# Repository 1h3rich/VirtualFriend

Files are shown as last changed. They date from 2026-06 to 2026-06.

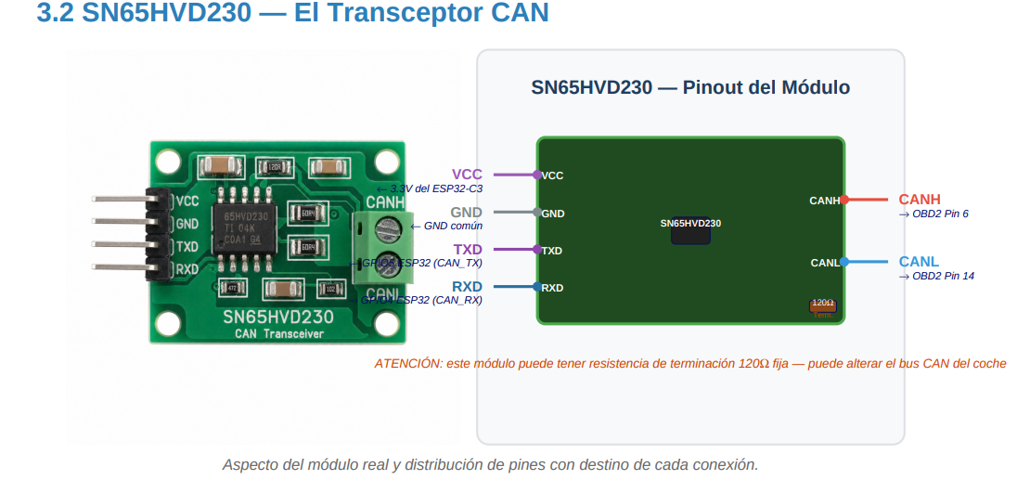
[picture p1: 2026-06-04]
VirtualFriendInf/Diagramas/DiagramaTranceptorCan.png

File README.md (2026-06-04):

# VirtualFriend

Copiloto virtual fisico para coche, basado en **M5Stack CoreS3** (ESP32-S3).
Cara animada en pantalla, voz sarcastica generada por IA, reacciona al
movimiento del vehiculo (IMU) y al toque del usuario.

## Hardware

- **M5Stack CoreS3** — pantalla tactil 320x240, altavoz AW88298, dos micros
  ES7210, microSD, IMU BMI270, bateria, WiFi.

## Arquitectura

```
[IMU/Touch] -> CtrlTask -> AnimTask  (cara animada en SD)
                       \-> AiTask   -> Cloudflare Worker
                                           |-> OpenAI gpt-4o-mini / Whisper
                                           \-> ElevenLabs TTS
[Touch]    -> MicTask   -> graba 3s WAV    -> AiTask -> Worker /listen
```

### Tareas FreeRTOS

| Tarea | Nucleo | Prio | Stack  | Funcion |
|---|---|---|---|---|
| AnimTask  | 0 | 2 | 20 KB  | reproduce GIF idle, eventos y expresiones |
| AiTask | 0 | 1 | 28 KB  | HTTP POST al Worker, TTS |
| MicTask | 1 | 1 | 12 KB  | grabacion I2S, genera WAV |
| CtrlTask  | 1 | 1 | 8 KB | IMU, touch, dispatch de eventos |

Sincronizacion: `g_audioMutex` serializa el acceso al I2S (mic/speaker
comparten bus). `g_micActive` y `g_aiThinking` activan los overlays en
pantalla.

## Estructura

```
src/
  main.cpp              entrypoint, setup y CtrlTask
  Config.h              umbrales IMU, credenciales WiFi/Worker
  AnimationPlayer.*     reproduccion de GIFs + fallback vectorial
  FaceRenderer.*        cara vectorial cuando no hay SD
  ExpressionManager.*   parametros de expresion (ojos, boca, color)
  SensorMonitor.*       IMU: detecta acelerada, frenada, bache
  MicManager.*          grabacion 3s WAV @ 16kHz
  SpeechManager.*       decode MP3 (minimp3) + reproduccion
  AiManager.*           cliente HTTP del Worker, gestiona expresiones IA
  SoundManager.*        beeps de eventos y alertas
  minimp3.h             header-only MP3 decoder
```

## Compilar y subir

```sh
pio run                       # compilar
pio run --target upload       # compilar + subir al M5Stack
pio device monitor            # ver logs por serie
```

El puerto USB suele estar en `/dev/ttyACM0` o `/dev/ttyACM1`.
Ajusta `upload_port` / `monitor_port` en `platformio.ini` si cambia.

## Endpoints del Worker

- `POST /` — evento de sensor (HARD_ACCEL, HARD_BRAKE, BUMP).
- `POST /listen` — audio WAV del micro -> Whisper -> respuesta IA.

Ambos devuelven `audio/mpeg` (MP3 22050Hz) con headers `X-VF-Expression`
y `X-VF-Sound`.

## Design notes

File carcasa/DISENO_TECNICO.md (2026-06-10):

# VirtualFriend — Diseño Técnico de Carcasa

## 1. Concepto general

Carcasa en dos piezas para salpicadero de coche. Cuerpo principal con apertura frontal
(pantalla + rejilla altavoz) y tapa trasera desmontable con tornillos M3. El conjunto
está inclinado 8° hacia atrás para que la pantalla y el altavoz apunten directamente
al conductor/copiloto. El zócalo de base sobresale lateralmente para mayor estabilidad
y admite velcro o adhesivo 3M en la cara inferior.

---

## 2. Distribución interna de componentes

```
┌─────────────────────────────────────────────────────────────────────┐
│  FRONTAL (cara visible)                                             │
│                                                                     │
│  ┌───────────────────────────────────────────────────────────────┐  │
│  │  VENTANA PANTALLA M5Stack  50.5 × 42 mm                      │  │
│  │                                                               │  │
│  │  Asiento M5Stack CoreS3                56.5 × 56.5 × 32.5    │  │
│  │  (retenido por 3 paredes laterales + base)                    │  │
│  └───────────────────────────────────────────────────────────────┘  │
│                                                                     │
│  ┌───────────────────────────────────────────────────────────────┐  │
│  │  REJILLA ALTAVOZ  72 × 33 mm (ranuras verticales 1.5mm)      │  │
│  │  Asiento altavoz con labio perimetral + espacio acústico      │  │
│  │  Amplificador MAX98357A en repisa lateral derecha             │  │
│  └───────────────────────────────────────────────────────────────┘  │
│                                                                     │
│  ┌─────────────────────────────────────────────────────────────┐    │
│  │  ZONA CAN/OBD (expansión futura)  40 × 35 mm               │    │
│  │  Delimitada por nervios internos, accesible desde tapa      │    │
│  └─────────────────────────────────────────────────────────────┘    │
└─────────────────────────────────────────────────────────────────────┘
```

---

## 3. Medidas exteriores

| Dimensión | Valor |
|---|---|
| Ancho | 112 mm |
| Alto | 88 mm |
| Profundidad | 52 mm |
| Radio esquinas | 4 mm |
| Inclinación | 8° |
| Zócalo (sobresale) | +8 mm c/lado |

---

## 4. Medidas internas (espacio útil)

| Zona | Dimensión |
|---|---|
| Interior general | 106.4 × 82.4 × 45.2 mm |
| Hueco M5Stack | 56.5 × 56.5 × 32.5 mm  |
| Hueco altavoz | 72 × 33 × 8 mm |
| Zona amplificador | 25 × 18 × 10 mm |
| Zona CAN/OBD futura | 40 × 35 × 20 mm |
| Paredes | 2.8 mm general / 3.0 mm base |

---

## 5. Ubicación del M5Stack CoreS3

- Posición: zona superior del cuerpo, centrado horizontalmente.
- Retenido por 3 paredes interiores (izquierda, derecha, superior) de 1.5 mm de grosor.
- La cara frontal (pantalla) queda alineada con la apertura de la carcasa.
- Margen superior: 4 mm (para fácil extracción).
- Cables salen por la parte inferior hacia el compartimento del amplificador y CAN.

---

## 6. Ubicación del altavoz

- Posición: zona inferior frontal, debajo del M5Stack.
- Separación entre M5Stack y altavoz: 4 mm (para paso de cables y disipación).
- Orientación: cono mirando hacia frontal (hacia el conductor).
- Asiento con labio perimetral de 1.5 mm para sellar con junta de espuma/goma.
- Cámara acústica detrás: ~8 mm de profundidad antes de la zona de amplificador.
- Rejilla frontal: ranuras verticales de 1.5 mm con separación de 2.5 mm, margen perimetral 4 mm.
- El cono del altavoz no toca plástico ni cables (mínimo 2 mm libre).

---

## 7. Ubicación del MAX98357A

- Posición: repisa interior lateral derecha, entre el asiento del altavoz y la zona CAN.
- Altura: a 9 mm del suelo interior (encima del asiento del altavoz).
- Accesible sin extraer el M5Stack (abriendo la tapa trasera).
- Cables que salen:
  - 5V / GND desde M5Stack
  - BCLK, LRC/WS, DIN desde pines I2S del M5Stack
  - + / - hacia altavoz (corto recorrido, altavoz justo encima)

---

## 8. Hueco futuro Jack 3.5mm

- Posición: lateral izquierdo del cuerpo, a media altura de la zona M5Stack.
- El agujero está **marcado pero cerrado** en el diseño actual (pared sólida).
- Basta con taladrar Ø7 mm para instalar el conector jack.
- Espacio interior reservado para DAC PCM5102A (~20×15×5 mm) cerca de ese lateral.
- El jack **no** vendrá de la salida amplificada; vendrá del DAC I2S futuro.

---

## 9. Hueco futuro Módulo CAN/OBD

- Posición: zona inferior del compartimento interior.
- Dimensiones reservadas: 40 × 35 × 20 mm.
- Delimitada por dos nervios verticales de 1 mm de alto (marcadores visuales, no estructurales).
- Accesible directamente al abrir la tapa trasera.
- Salida de cable: ranura inferior trasera de 20×4 mm ya perforada para paso de cable OBD2.
- No interfiere con el prototipo actual.

---

## 10. Sistema de cierre con tornillos

- 4 columnas M3 en las esquinas interiores del cuerpo.
  - Diámetro exterior columna: 6.5 mm.
  - Agujero interior: 2.5 mm (para roscar con macho M3 o insertar inserto de calor M3).
  - Altura: 12 mm.
- Tapa trasera con 4 agujeros pasantes M3 + avellanado para cabeza.
- Tornillos recomendados: **M3×12 cabeza avellanada** (ISO 10642 / DIN 7991).
- El labio de encaje (2 mm de profundidad, tolerancia 0.25 mm) centra la tapa antes de atornillar.

---

## 11. Sistema de fijación al salpicadero

El zócalo sobresale 8 mm por cada lado respecto al cuerpo. La cara inferior es plana.
Opciones de fijación:

| Opción | Descripción |
|---|---|
| Velcro industrial | Pegar en la base, pareja en el salpicadero |
| Adhesivo 3M VHB | Cinta doble cara de alta resistencia |
| Base antideslizante | Lámina de silicona pegada en la base (temporal) |
| Soporte articulado  | Adaptar brazo de ventosa/rejilla con tornillo M4  |

Para el soporte articulado: el zócalo tiene espacio suficiente para añadir un agujero
M4 centrado (modificar el parámetro y regenerar el STL).

---

## 12. Recomendaciones de impresión 3D

| Parámetro | Cuerpo principal | Tapa trasera |
|---|---|---|
| Material | PETG / ASA | PETG / ASA |
| Orientación | Cara frontal abajo | Cara exterior abajo |
| Capas | 0.2 mm | 0.2 mm |
| Relleno | 25–30% | 20% |
| Perímetros | 3–4 | 3 |
| Soportes | No necesarios | No necesarios |
| Temperatura cama | 70°C (PETG) / 100°C (ASA) | igual |

- **No se necesitan soportes** con la orientación indicada.
- La rejilla del altavoz y la ventana de pantalla se imprimen sin soportes al orientar cara frontal abajo.
- Las columnas de tornillo se imprimen en vertical → buen acabado de agujero.
- Si se usa ASA: imprimir en recinto cerrado para evitar warping.

---

## 13. Lista de piezas necesarias

### Piezas impresas
| Pieza | Cantidad | Archivo |
|---|---|---|
| Cuerpo principal | 1 | virtualfriend_carcasa.scad (PIEZA="cuerpo") |
| Tapa trasera | 1 | virtualfriend_carcasa.scad (PIEZA="tapa") |

### Ferretería
| Elemento | Cantidad | Especificación |
|---|---|---|
| Tornillo M3×12 avellanado| 4 | ISO 10642 acero/inox |
| Inserto de calor M3 | 4 | Ø4.5mm×5.7mm (opcional, mejor rosca) |
| Junta espuma altavoz | 1 | Cortar a medida 72×33mm, Ø3mm grosor |
| Velcro industrial | 1 par | 50×25mm mínimo |

### Electrónica interna
| Componente | Cantidad | Notas |
|---|---|---|
| M5Stack CoreS3 K128 | 1 | Ya disponible |
| Amplificador MAX98357A | 1 | Módulo breakout |
| Altavoz 4Ω/3W 70×31mm | 1 | CQRobot Ocean o equivalente |
| Cable Dupont hembra 6pin | 1 | Para conexión amp-M5Stack |

### Futuras ampliaciones (no necesarias ahora)
| Componente | Cantidad | Notas |
|---|---|---|
| Conector Jack 3.5mm PJ-3 | 1 | Montaje en panel, Ø7mm |
| DAC PCM5102A | 1 | Módulo breakout |
| Módulo CAN SN65HVD230 | 1 | Ya previsto en el proyecto |

---

## 14. Posibles problemas del diseño

| Problema | Causa probable | Solución |
|---|---|---|
| M5Stack no encaja / muy ajustado | Tolerancia de impresión variable  | Ajustar m5_w/m5_h ±0.3 mm en el .scad |
| Tapa trasera no cierra bien | Shrinkage del material | Reducir tapa_lip_gap de 0.25 a 0.15  |
| Resonancias del altavoz | Cámara acústica pequeña | Añadir espuma acústica en la cámara |
| Columnas de tornillo se rompen | Impresión a baja densidad | Subir perímetros a 4, relleno 40% |
| Calor en coche (verano, ASA) | PLA o PETG a >60°C | Usar ASA, evitar exposición solar directa |
| USB-C inaccesible | Posición errónea según orientación| Verificar antes de imprimir con mockup de papel |

---

## 15. Mejoras para una versión 2

1. **Inclinación variable**: añadir cuña de base intercambiable (5°, 10°, 15°) para distintas posiciones de salpicadero.
2. **Soporte articulado integrado**: brazo tipo "cuello de cisne" para montaje en rejilla AC o ventosa.
3. **Cámara acústica sellada**: compartimento trasero del altavoz completamente sellado con abertura tipo bass-reflex (tubo de 8mm).
4. **Gestión térmica**: ranuras de ventilación pasiva en laterales superiores.
5. **LED de estado**: agujero lateral pequeño (Ø5mm) para LED indicador de encendido/OBD.
6. **Tapa modular CAN**: cuando llegue el módulo CAN, tapa trasera con conector DB9 o conector OBD integrado.
7. **Canal de cables**: guías internas para organizar el cableado limpiamente.
8. **Etiqueta grabada**: texto "VirtualFriend" en relieve en la tapa trasera (fácil en OpenSCAD).

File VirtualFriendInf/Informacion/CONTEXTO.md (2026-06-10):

# CONTEXTO DEL PROYECTO — VirtualFriend
> Leer este archivo al inicio de cada sesión para tener contexto completo.
> Actualizar al final de cada sesión con lo que se ha hecho.

---

## QUÉ ES ESTE PROYECTO

**VirtualFriend**: copiloto virtual físico para coche. Un pequeño dispositivo con pantalla que acompaña al conductor, muestra una cara animada, tiene personalidad humorística/sarcástica, reacciona al movimiento del vehículo y, en fases avanzadas, lee datos reales del coche por OBD2/CAN.

**Carpeta del proyecto**: `~/virtualfriend/`
**Lenguaje**: C++ / Arduino Framework
**Objetivo actual**: prototipo funcional y ampliable, no producto comercial.

---

## HARDWARE

### Dispositivo principal (cara/voz/IA)
- **M5Stack CoreS3 K128**
  - ESP32-S3, pantalla táctil, Wi-Fi, BLE, altavoz, 2 micrófonos, cámara, IMU, magnetómetro, RTC, microSD, batería

### Dongle OBD2 propio (lector del coche)
- **ESP32-C3** — microcontrolador, TWAI/CAN + BLE
- **SN65HVD230** — transceptor CAN (traduce lógica 3.3V ↔ bus CAN del coche)
- **Conversor DC-DC 12V→5V** — alimentación desde OBD2 pin 16
- **Fusible 1A** — protección en el cable +12V
- **Cable OBD2 macho a cables abiertos**
- **Caja plástica ~100×60×30 mm** (nunca metálica)

### Pines OBD2 usados
| Pin | Señal | Descripción |
|-----|---|---|
| 4/5 | GND | Masa |
| 6 | CAN-H | Bus CAN High |
| 14  | CAN-L | Bus CAN Low |
| 16  | +12V  | Alimentación directa batería |

---

## ARQUITECTURA DEL SISTEMA

```
Coche → Puerto OBD2
  ↓ cable físico
Dongle OBD2 (ESP32-C3 + SN65HVD230)
  ↓ BLE (datos limpios, no tramas crudas)
M5Stack CoreS3
  → cara, voz, frases, IA, reacciones
```

**Datos que lee el dongle (fase inicial)**:
- RPM: PID 0x0C → `((A*256)+B)/4`
- Velocidad: PID 0x0D → `A` km/h
- Temperatura refrigerante: PID 0x05 → `A-40` °C
- Voltaje: PID 0x42 → `((A*256)+B)/1000` V

**Velocidad CAN**: 500 kbps (probar 250 si no responde)
**ID petición OBD2**: 0x7DF | **ID respuesta**: 0x7E8–0x7EA

**Formato BLE enviado por dongle**:
```
rpm=1850;speed=72;coolant=91   (texto simple para prototipo)
```
o JSON en fases avanzadas.

---

## PERSONALIDAD DEL COPILOTO

- Tono: humorístico, sarcástico, carismático, útil
- Se pone serio ante avisos importantes
- Ejemplos:
  - Aceleración fuerte → "Tranquilo, Fernando Alonso, que esto no es Nürburgring."
  - Temperatura alta → "Ojo. El motor se está calentando más de la cuenta."
  - Bache → "Ese bache no era parte del trayecto, era contenido descargable."

---

## FASES DE DESARROLLO

| Fase | Estado | Objetivo |
|---|---|---|
| 1 | Pendiente | M5Stack: cara animada, expresiones, frases, sonido, IMU. Sin OBD2. |
| 2 | Pendiente | Dongle: ESP32-C3 + SN65HVD230, leer RPM por Serial Monitor. Sin BLE. |
| 3 | Pendiente | Dongle: leer RPM + velocidad + temperatura + voltaje |
| 4 | Pendiente | BLE: dongle envía datos, M5Stack recibe |
| 5 | Pendiente | Integración: datos del coche cambian expresiones y activan frases |
| 6 | Pendiente | Caja física, montaje final, pruebas reales en coche |

---

## ESTRUCTURA DE CÓDIGO PREVISTA

```
virtualfriend/
├── dongle_obd2/
│   ├── src/
│   │   ├── main.cpp
│   │   ├── Config.h          ← pines CAN_TX/RX, velocidad CAN, nombre BLE
│   │   ├── VehicleData.h     ← struct {rpm, speed, coolantTemp, batteryVoltage, valid}
│   │   ├── CanManager.h/cpp  ← init TWAI, send/receive tramas
│   │   ├── ObdReader.h/cpp   ← pedir PIDs, convertir bytes a valores
│   │   └── BleServer.h/cpp   ← servidor BLE GATT, notificaciones
│   └── platformio.ini
└── m5stack_copilot/
    └── src/
        ├── main.cpp
        ├── FaceRenderer.h/cpp
        ├── ExpressionManager.h/cpp
        ├── PhraseEngine.h/cpp
        ├── SoundManager.h/cpp
        ├── SensorMonitor.h/cpp   ← IMU para baches/frenazos
        └── BleClient.h/cpp       ← recibir datos del dongle
```

**Config.h del dongle (orientativo)**:
```cpp
#define CAN_TX_PIN 5
#define CAN_RX_PIN 4
#define CAN_SPEED  500000
#define BLE_DEVICE_NAME "VirtualFriend_OBD"
```

---

## LIBRERÍAS PREVISTAS

| Dispositivo | Librería |
|---|---|
| ESP32-C3 dongle | ESP-IDF TWAI, Arduino BLE |
| Datos OBD2 complejos (VIN, DTCs largos) | TWAI_ISO-TP |
| M5Stack CoreS3 | M5Unified, BLE client |

---

## REGLAS DE SEGURIDAD (CRÍTICAS)

- Solo lectura de PIDs OBD2 estándar
- NUNCA escribir en ECUs, borrar DTCs, controlar ABS/airbag/DSG/inmovilizador
- NUNCA comandos propietarios del fabricante
- Siempre fusible 1A en +12V
- Medir con multímetro antes de conectar al coche (salida DC-DC debe ser 5.0V ±0.2V)
- Caja plástica, no metálica
- Si el coche muestra aviso → desconectar inmediatamente
- Si algo se calienta → desconectar inmediatamente

---

## LO QUE SE HA HECHO HASTA AHORA

### Sesión 1 (2026-06-02/03)
- [x] Leído y analizado `ConfeccionOBD2.txt` con el manual técnico del dongle
- [x] Generado PDF visual completo: `/home/rich/Escritorio/Proyecto/Manual_OBD2_Dongle.pdf`
  - Portada, índice, 12 capítulos, diagramas dibujados con reportlab:
    - Conector OBD2 con pines coloreados
    - Diagrama de bloques del sistema
    - Esquema de cableado completo estilo PCB
    - Estructura de trama CAN/OBD2
  - Tablas de pines, PIDs, conexiones, velocidades CAN
  - Pasos de montaje numerados, protocolo de pruebas, troubleshooting
- [x] Creado este archivo CONTEXTO.md

### Sesión 2 (2026-06-03)
- [x] Generado PDF de soldadura: `/home/rich/Escritorio/Proyecto/Manual_Soldadura_OBD2.pdf`
  - 12 imágenes reales generadas con IA (GPT-Image-2) de todos los componentes
  - Pinouts dibujados: ESP32-C3, SN65HVD230, DC-DC
  - Código de colores de cables detallado
  - Técnica de soldadura paso a paso con fotos
  - 9 pasos de montaje: fusible → DC-DC → ESP32 → SN65 → CAN → GND → verificación → caja
  - Tabla de verificaciones con multímetro
  - Resumen visual de todas las conexiones
- [x] Actualizado CONTEXTO.md

### Sesión 3 (2026-06-03)
- [x] Revisado `DiagramaDeCableado.png` original — errores detectados: CAN-H/CAN-L iban al DC-DC en vez del SN65, SN65 debajo del DC-DC con líneas confusas, diagrama recortado a la derecha (sin M5Stack), labels solapados
- [x] Generadas versiones corregidas del diagrama:
  - v2: `/home/rich/Escritorio/Proyecto/DiagramaDeCableado_v2.png` — layout con M5Stack, rutas CAN correctas (solapamientos parciales)
  - v3–v5: iteraciones con diseño de dos zonas (alimentación/CAN), calles Y exclusivas por señal, layout sin solapamientos
  - **Final**: `/home/rich/Escritorio/Proyecto/DiagramaDeCableado_v5.png` — aprobado, limpio
    - Canvas 1920×980, zona azul (alimentación) + zona verde (CAN/señales)
    - DC-DC y SN65HVD230 apilados (mismo X, diferente Y con hueco visual)
    - Cada señal en su propia calle Y: +12V=160, +5V=240, GND=340, 3V3=410, CAN-H=560, CAN-L=640, TX=720, RX=800, BLE=900
    - Leyenda completa + caja de puntos críticos en esquina derecha
- [x] Scripts generadores en `/tmp/gen_diagrama_v3.py` a `v5.py`
- [x] Revisado y rehecho `DiagramaTranceptorCan.png`:
  - Original: labels solapados, "RXDR" en vez de RXD, texto cortado, mal contraste
  - **Final**: `/home/rich/Escritorio/Proyecto/DiagramaTranceptorCan_v2.png`
    - Script en `/tmp/gen_diagrama_transceptor.py`
    - Foto real del módulo SN65HVD230 (AI-generada)
    - Bloque ESP32 (izq) + SN65 (centro, LÓGICA/BUS CAN) + OBD2 (der)
    - Cables con colores, flechas de dirección y pill labels
    - Nota sobre resistencia terminación 120Ω y cómo comprobarla

### Sesión 4 (2026-06-03)
- [x] Cloudflare Worker desplegado y funcional
  - Worker en `~/Proyectos/virtualfriend-worker/`
  - URL pública: `https://virtualfriend-worker.rykhjob.workers.dev`
  - Secrets en Cloudflare: `GEMINI_API_KEY` y `DEVICE_TOKEN`
  - DEVICE_TOKEN: `(ver src/Secrets.h — no publicar)`
  - IA: Gemini 2.5 Flash con thinking desactivado (`thinkingBudget: 0`)
  - Tests pasando (6/6)
  - Documentación en `Escritorio/Proyecto/cloudflare/CLOUDFLARE_WORKER.md`
- [x] Problema detectado y resuelto: Gemini 2.5 Flash consumía todos los tokens pensando → se desactivó el modo thinking
- [x] Problema TLS en CachyOS: TLS 1.3 + ECH falla en este equipo con curl. Usar `--tlsv1.2 --tls-max 1.2` para pruebas locales. El M5Stack no tendrá este problema.

### Sesiones 5-7 (2026-06-03/04) — Implementación Fase 1 completa
- [x] Estructura `virtualfriend/m5stack_copilot/` con PlatformIO, env `m5stack-cores3`
- [x] **FaceRenderer**: cara vectorial (ojos+boca) con 8 formas de ojo y 7 de boca; modo de fallback cuando no hay SD
- [x] **ExpressionManager**: 7 expresiones (NEUTRAL/HAPPY/SARCASTIC/SURPRISED/ALERT/SLEEPING/ANGRY) con FaceParams
- [x] **SensorMonitor**: lectura IMU BMI270 a 25Hz; detección de HARD_ACCEL/HARD_BRAKE/BUMP con umbrales calibrados + cooldown 3s
- [x] **AnimationPlayer**: reproducción de GIFs desde SD con AnimatedGIF; sprite M5Canvas 320×240 en PSRAM; bucle interrumpible; pickPath para variantes aleatorias
- [x] **SoundManager**: 5 efectos (STARTUP/BUMP/ACCEL/BRAKE/ALERT) con mutex trylock para no romper I2S
- [x] **MicManager**: grabación 3s WAV @16kHz mono en PSRAM; mutex con timeout 20s; retry de record(); indicador "HABLA AHORA" inmediato al tocar; visibilidad mínima 2000ms
- [x] **SpeechManager**: decode MP3 con minimp3 (header-only); reproducción via M5.Speaker.playRaw; espera 600ms post-audio dentro del mutex (evita eco→Whisper)
- [x] **AiManager**: cliente HTTPS al Cloudflare Worker; dos endpoints (`/` para eventos, `/listen` para audio); flag `g_aiThinking` con overlay "PENSANDO..."; beep de alerta en errores; expresiones IA `X-VF-Expression` → AnimEvent → GIF o vector fallback
- [x] Compilación OK: 22.6% RAM, 17% Flash. Subido al M5Stack.

### Migración a proyecto VS Code (2026-06-04)
- [x] Movido todo el código desde `~/virtualfriend/m5stack_copilot/` a `~/VirtualFriend/` (proyecto Git original)
- [x] Reemplazado `platformio.ini` Wokwi/esp32dev por `m5stack-cores3`
- [x] Eliminados `wokwi.toml` y `diagram.json` (CoreS3 no soportado por Wokwi)
- [x] Eliminado `PhraseEngine.h/cpp` (la IA genera las frases)
- [x] README.md actualizado con arquitectura, tareas FreeRTOS y flujo
- [x] Commit `9570856` en main: "Fase 1: M5Stack CoreS3 firmware completo"

### Próxima sesión (Fase 2: dongle OBD2)
- [ ] Crear `dongle_obd2/` con PlatformIO env ESP32-C3
- [ ] CanManager: init TWAI a 500kbps, send/receive tramas
- [ ] ObdReader: PIDs 0x0C/0x0D/0x05/0x42, conversión bytes→valores
- [ ] Probar con coche real (lectura sin BLE primero)

---

## NOTAS TÉCNICAS IMPORTANTES

- El SN65HVD230 puede tener resistencia de terminación CAN de 120Ω fija → puede interferir con el bus del coche → revisar si hay problemas de comunicación
- Alimentar ESP32-C3 por USB y VIN/5V simultáneamente puede ser problemático según la placa → en pruebas, usar solo una fuente
- No confiar en colores del cable OBD2 → identificar pines por posición física
- Pin 1 del OBD2 = arriba izquierda, pin 16 = abajo derecha
- Frecuencia de consultas OBD2 no debe ser excesiva → puede saturar el bus o provocar avisos en el coche

---
*Actualizado: 2026-06-04 (Fase 1 completa, código en ~/VirtualFriend/)*

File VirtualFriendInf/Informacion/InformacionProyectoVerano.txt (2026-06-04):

# Resumen del prototipo: Copiloto Virtual para coche

## 1. Descripción general del proyecto

El proyecto consiste en crear un **copiloto virtual físico para coche**, con aspecto de pequeño compañero digital. La idea es que acompañe al conductor durante los viajes, muestre una cara animada en pantalla, tenga personalidad humorística y sarcástica, pueda reaccionar al movimiento del vehículo y, en fases posteriores, leer datos reales del coche mediante OBD2/CAN.

El proyecto está pensado para desarrollarse en la carpeta:

```txt
virtualfriend
```

El lenguaje principal será:

```txt
C++ / Arduino Framework
```

El objetivo inicial no es crear un producto comercial perfecto, sino un **prototipo funcional y ampliable**.

---

## 2. Personalidad del copiloto virtual

El copiloto debe tener un tono:

```txt
Humorístico
Sarcástico
Carismático
Útil cuando haga falta
Capaz de ponerse serio ante avisos importantes
```

Ejemplo de comportamiento:

* Si el conductor acelera mucho:
  “Tranquilo, Fernando Alonso, que esto no es Nürburgring.”

* Si detecta temperatura alta del motor:
  “Ojo. El motor se está calentando más de la cuenta.”

* Si detecta un bache o frenazo:
  “Ese bache no era parte del trayecto, era contenido descargable.”

La personalidad no debe impedir que dé avisos importantes de forma clara.

---

## 3. Hardware principal del copiloto

El dispositivo principal elegido es:

```txt
M5Stack CoreS3 K128
```

Se eligió esta placa porque incluye muchos elementos ya integrados:

```txt
Pantalla táctil
ESP32-S3
Wi-Fi
BLE
Altavoz
Doble micrófono
Cámara
Sensor de proximidad/luz
IMU / acelerómetro / giroscopio
Magnetómetro
RTC
microSD
Batería/base
```

Este dispositivo será la parte visible del copiloto:

```txt
M5Stack CoreS3 = cara, voz, pantalla, IA, personalidad y reacciones
```

---

## 4. Prototipo Nivel 1

El primer prototipo debe ser simple. No debe depender todavía del OBD2 ni de datos reales del coche.

El Prototipo 1 consta de:

```txt
Encendido
Pantalla con cara
Cambio de expresiones
Frases predefinidas
Sonidos simples
Reacción a movimiento
```

### Objetivo del Prototipo 1

Crear un dispositivo que:

```txt
Se encienda correctamente
Muestre una cara animada
Cambie de expresión
Reproduzca frases o sonidos simples
Reaccione al movimiento usando sensores internos
```

### Componentes necesarios para Prototipo 1

```txt
M5Stack CoreS3 K128
Animaciones de cara
Frases predefinidas
Sistema básico de sonido
Lectura de sensores internos
Código en C++
```

### Cómo se abordará cada parte

#### Encendido

El M5Stack debe iniciar correctamente y mostrar una pantalla de bienvenida.

Ejemplo:

```txt
"Copiloto iniciado"
"Cargando personalidad..."
```

#### Pantalla con cara

La pantalla mostrará una cara simple. Puede empezar siendo muy básica:

```txt
Ojos normales
Ojos enfadados
Ojos sorprendidos
Ojos dormidos
Boca simple
```

No hace falta empezar con animaciones complejas. Primero importa que se pueda cambiar de estado visual.

#### Cambio de expresiones

El dispositivo tendrá distintos estados:

```txt
Normal
Feliz
Sarcástico
Alerta
Dormido
Asustado
Pensando
```

Cada estado cambiará la cara mostrada en pantalla.

#### Frases predefinidas

Al principio no se usará IA generativa. Se programará una lista de frases predefinidas.

Ejemplo:

```cpp
"Vaya conducción. No sé si aplaudir o rezar."
"Todo bajo control. Supuestamente."
"Estoy despierto. Más que algunos copilotos humanos."
```

#### Sonidos simples

El CoreS3 podrá reproducir sonidos breves:

```txt
Beep
Sonido de alerta
Sonido de confirmación
Sonido de arranque
Sonido de reacción
```

#### Reacción a movimiento

El M5Stack CoreS3 usará sus sensores internos para detectar:

```txt
Baches
Frenazos
Curvas bruscas
Golpes
Movimiento repentino
```

Esto no necesita OBD2. Se hace con acelerómetro/giroscopio.

Ejemplo:

```txt
Si detecta aceleración fuerte → cambia a cara sorprendida
Si detecta golpe/bache → reproduce frase sarcástica
Si no hay movimiento durante un rato → modo dormido
```

---

## 5. Prototipo Nivel 2: conexión con datos del coche

La siguiente fase consiste en leer datos reales del vehículo.

Hay dos opciones:

```txt
1. Adaptador OBD2 BLE comercial
2. Dongle OBD2 propio
```

Se ha decidido explorar la opción de **crear un dongle propio**, para no depender de un adaptador comercial y para aprender cómo funcionaría una versión de producción.

---

## 6. Arquitectura general con OBD2

La arquitectura sería:

```txt
Coche
↓
Puerto OBD2 debajo del volante
↓
Dongle OBD2 propio
↓ BLE
M5Stack CoreS3
↓
Cara, voz, frases, IA y reacciones
```

El puerto OBD2 permite acceder a datos básicos del coche mediante CAN/OBD2.

Datos útiles:

```txt
RPM
Velocidad
Temperatura del refrigerante
Voltaje
Carga del motor
Códigos de error
```

No se pretende leer “todo el coche”. El objetivo inicial es leer datos OBD2 estándar.

---

## 7. Dongle OBD2 propio

El dongle propio sería un pequeño dispositivo conectado al puerto OBD2 del coche. Su función será leer datos básicos del vehículo y enviarlos por BLE al M5Stack CoreS3.

La idea es:

```txt
Dongle OBD2 = lector técnico del coche
M5Stack CoreS3 = interfaz, personalidad y comportamiento
```

### Componentes del dongle propio

```txt
ESP32-C3
Módulo CAN SN65HVD230
Cable OBD2 macho a cables abiertos
Conversor 12V a 5V
Fusible / portafusible
Cables Dupont
Caja pequeña
Soldador / estaño / termorretráctil
Multímetro
```

---

## 8. Para qué sirve cada componente

### M5Stack CoreS3 K128

Es el cuerpo principal del copiloto.

Sirve para:

```txt
Mostrar la cara animada
Reproducir voz o sonidos
Escuchar mediante micrófono
Usar Wi-Fi para futuras APIs
Conectarse por BLE al dongle
Detectar movimiento con sus sensores internos
Ejecutar la lógica principal del personaje
```

---

### ESP32-C3

Es el cerebro del dongle OBD2.

Sirve para:

```txt
Leer datos del coche
Procesar respuestas OBD2/CAN
Enviar datos limpios por BLE al M5Stack
```

El ESP32-C3 no será visible para el usuario. Irá dentro de una pequeña caja conectada al OBD2.

---

### SN65HVD230 CAN Module

Es el transceptor CAN.

Sirve para que el ESP32-C3 pueda comunicarse físicamente con el bus CAN del coche.

El ESP32-C3 puede gestionar CAN/TWAI a nivel lógico, pero necesita un transceptor para conectarse a los cables reales del coche:

```txt
CAN-H
CAN-L
```

Sin este módulo, el ESP32-C3 no puede hablar correctamente con la red CAN del vehículo.

---

### Cable OBD2 macho a cables abiertos

Es el enchufe físico al coche.

Sirve para conectar el dongle al puerto OBD2 sin desmontar nada.

Pines importantes:

```txt
Pin 6  → CAN-H
Pin 14 → CAN-L
Pin 16 → +12V
Pin 4/5 → GND / masa
```

Este cable permite construir el dongle sin tener que desmontar salpicadero ni buscar cables CAN internos.

---

### Conversor 12V a 5V

El coche entrega 12V por el puerto OBD2, pero el ESP32-C3 no puede recibir 12V directamente.

Este módulo sirve para:

```txt
Bajar de 12V del coche a 5V seguros
Alimentar el ESP32-C3
Evitar quemar la placa
```

Conexión:

```txt
OBD2 pin 16 +12V
↓
Fusible
↓
Conversor 12V a 5V
↓
ESP32-C3
```

---

### Fusible / portafusible

Sirve para proteger el prototipo y el coche en caso de cortocircuito.

Debe ir entre el positivo del OBD2 y el conversor:

```txt
OBD2 pin 16 +12V
↓
Fusible 1A
↓
Conversor 12V a 5V
```

Fusible recomendado:

```txt
1A
```

También puede servir:

```txt
500mA
2A
```

No usar fusibles grandes tipo 20A o 30A para este circuito.

---

### Cables Dupont

Sirven para conectar módulos durante las pruebas.

Conectan:

```txt
ESP32-C3 ↔ SN65HVD230
SN65HVD230 ↔ cable OBD2
Conversor 5V ↔ ESP32-C3
```

Para pruebas están bien. Para un montaje más estable en coche, mejor soldar y aislar.

---

### Caja pequeña

Sirve para meter dentro el dongle y evitar que las placas y cables queden sueltos debajo del volante.

Tamaño recomendado:

```txt
100 x 60 x 25 mm
100 x 60 x 30 mm
```

Debe ser:

```txt
Plástica
No metálica
Fácil de taladrar
Con tapa
Suficientemente amplia para prototipo
```

---

### Soldador, estaño y termorretráctil

Sirven para dejar conexiones firmes y seguras.

Los cables Dupont son útiles para pruebas, pero no deberían quedar como montaje final dentro del coche.

---

### Multímetro

Es importante para comprobar:

```txt
Que el conversor entrega 5V y no 12V
Que no hay cortocircuitos
Qué cable corresponde a cada pin del OBD2
Que GND está bien conectado
```

Antes de conectar el ESP32-C3 al conversor, hay que medir la salida.

---

## 9. Conexión eléctrica del dongle

Esquema básico:

```txt
OBD2 pin 6  CAN-H  → CAN-H del SN65HVD230
OBD2 pin 14 CAN-L  → CAN-L del SN65HVD230

OBD2 pin 16 +12V
↓
Fusible 1A
↓
Conversor 12V a 5V
↓
5V del ESP32-C3

OBD2 pin 4/5 GND
↓
GND común del conversor, ESP32-C3 y SN65HVD230

ESP32-C3 GPIO TX CAN → TXD del SN65HVD230
ESP32-C3 GPIO RX CAN → RXD del SN65HVD230
```

---

## 10. Comunicación OBD2/CAN

Para leer datos básicos no hace falta interpretar todo el CAN del coche.

Se pueden hacer consultas OBD2 estándar.

Ejemplo: pedir RPM.

Petición CAN:

```txt
ID: 0x7DF
Datos: 02 01 0C 00 00 00 00 00
```

Significado:

```txt
02 = longitud de datos útiles
01 = modo OBD2 para datos actuales
0C = PID de RPM
```

Respuesta esperada:

```txt
ID: 0x7E8
Datos: 04 41 0C A B 00 00 00
```

Cálculo:

```txt
RPM = ((A * 256) + B) / 4
```

Otros PIDs útiles:

```txt
010C → RPM
010D → velocidad
0105 → temperatura refrigerante
010F → temperatura de admisión
0111 → posición del acelerador
03   → códigos de error
```

---

## 11. Software recomendado

Para el ESP32-C3:

```txt
Arduino Framework o ESP-IDF
TWAI/CAN
BLE
```

Librería/referencia útil:

```txt
TWAI_ISO-TP
```

Uso previsto:

```txt
TWAI directo → datos simples como RPM, velocidad y temperatura
TWAI_ISO-TP → mensajes más complejos como VIN o DTCs largos
```

Para el M5Stack CoreS3:

```txt
M5Unified / librerías de M5Stack
BLE client
Pantalla
Sonido
Sensores internos
Wi-Fi para futuras APIs
```

---

## 12. Comunicación entre dongle y M5Stack

El dongle ESP32-C3 enviará datos por BLE al M5Stack.

La idea es que el dongle no mande tramas crudas, sino datos limpios.

Ejemplo:

```json
{
  "rpm": 1850,
  "speed": 72,
  "coolant_temp": 91,
  "battery": 13.8,
  "errors": []
}
```

El M5Stack recibe esos datos y decide cómo reaccionar.

Ejemplo:

```txt
RPM > 3500 → cara sorprendida + frase sarcástica
Temperatura > 105 ºC → alerta seria
Velocidad alta → comentario
Error motor detectado → aviso
```

---

## 13. Fases de desarrollo recomendadas

### Fase 1: Prototipo visual básico

Objetivo:

```txt
Encender M5Stack
Mostrar cara
Cambiar expresiones
Reproducir frases
Detectar movimiento
```

Sin OBD2 todavía.

---

### Fase 2: Dongle OBD2 básico por Serial Monitor

Objetivo:

```txt
ESP32-C3 + SN65HVD230 + OBD2
Leer RPM
Mostrar RPM por Serial Monitor
```

Sin BLE todavía.

---

### Fase 3: Lectura de varios datos

Objetivo:

```txt
Leer RPM
Leer velocidad
Leer temperatura refrigerante
Leer voltaje si es posible
```

---

### Fase 4: Comunicación BLE

Objetivo:

```txt
ESP32-C3 envía datos por BLE
M5Stack CoreS3 recibe datos por BLE
```

---

### Fase 5: Integración con comportamiento del copiloto

Objetivo:

```txt
Los datos del coche cambian expresiones
Los datos del coche activan frases
Los sensores internos detectan baches/frenazos
```

---

### Fase 6: Caja y montaje físico

Objetivo:

```txt
Meter el dongle en caja
Aislar conexiones
Evitar cables sueltos
Hacer pruebas reales en coche
```

---

## 14. Casos de prueba ficticios

### Caso 1: Arranque correcto

Condición:

```txt
El M5Stack se enciende
```

Resultado esperado:

```txt
Muestra cara normal
Reproduce sonido de inicio
Muestra mensaje de sistema listo
```

---

### Caso 2: Cambio de expresión manual

Condición:

```txt
Se pulsa un botón o se activa un estado de prueba
```

Resultado esperado:

```txt
La cara cambia de normal a sarcástica
```

---

### Caso 3: Detección de bache

Condición:

```txt
El acelerómetro detecta movimiento brusco
```

Resultado esperado:

```txt
Cara sorprendida
Sonido breve
Frase sarcástica
```

---

### Caso 4: Lectura de RPM

Condición:

```txt
El dongle envía rpm = 3200
```

Resultado esperado:

```txt
El M5Stack muestra expresión alerta/sarcástica
Puede lanzar frase relacionada con revoluciones
```

---

### Caso 5: Temperatura alta

Condición:

```txt
coolant_temp > 105
```

Resultado esperado:

```txt
El copiloto cambia a modo alerta
Da un aviso claro y serio
```

---

### Caso 6: Sin conexión BLE

Condición:

```txt
El M5Stack no encuentra el dongle
```

Resultado esperado:

```txt
El copiloto sigue funcionando en modo básico
Muestra aviso: "Sin datos del coche"
No bloquea el sistema
```

---

### Caso 7: Datos inválidos

Condición:

```txt
El dongle envía valores nulos o erróneos
```

Resultado esperado:

```txt
El M5Stack ignora esos datos
Mantiene el último estado válido o vuelve a modo normal
```

---

## 15. Principios de seguridad

Durante el prototipo:

```txt
No escribir comandos peligrosos al coche
No intentar controlar módulos del vehículo
No modificar centralitas
No mandar comandos de programación
Solo lectura / consultas OBD2 estándar
Usar fusible
Medir voltajes antes de conectar
Aislar cables
No dejar placas sueltas bajo el volante
```

El objetivo es leer datos, no controlar el coche.

---

## 16. Objetivo final del prototipo

El objetivo final de esta fase es conseguir:

```txt
Un M5Stack CoreS3 funcionando como copiloto virtual
Un dongle OBD2 propio basado en ESP32-C3
Comunicación BLE entre dongle y M5Stack
Lectura básica de datos reales del coche
Reacciones visuales y sonoras según esos datos
Código organizado en C++ dentro de la carpeta virtualfriend
```

El prototipo debe priorizar:

```txt
Funcionamiento básico
Seguridad
Código entendible
Modularidad
Facilidad para ampliar
```

No debe priorizar todavía:

```txt
Carcasa comercial perfecta
IA avanzada
Compatibilidad con todos los coches
Certificación
Producción industrial
```

---

## 17. Lo que se necesita de Claude

Claude debe ayudar a:

```txt
Organizar el proyecto virtualfriend
Diseñar la estructura de carpetas
Crear código C++ entendible
Separar lógica de pantalla, sensores, frases, BLE y OBD2
Explicar cada archivo para que un principiante lo entienda
Crear pruebas ficticias sustituibles por datos reales
Preparar el código para M5Stack CoreS3
Preparar después el código para ESP32-C3 como dongle OBD2 BLE
```

El código debe estar comentado y explicado de forma didáctica.

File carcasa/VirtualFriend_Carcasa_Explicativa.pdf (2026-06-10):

VirtualFriend — Carcasa M5Stack CoreS3 K128 | Documentación técnica 3D

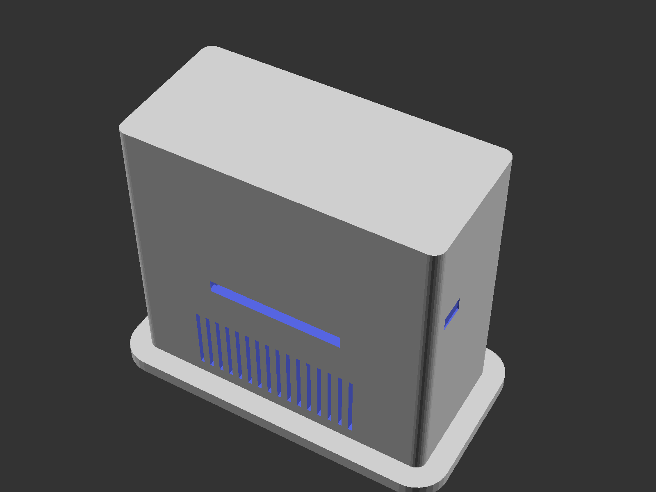
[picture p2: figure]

Proyecto VirtualFriend · Copiloto de conducción M5Stack + OBD2 | Página 1

# VirtualFriend

### Carcasa imprimible en 3D — M5Stack CoreS3 K128

Documentación técnica · Distribución interior de componentes · Guía de montaje

Vista general — cuerpo frontal + tapa trasera desmontable

## 1. Introducción

Esta carcasa ha sido diseñada específicamente para albergar el M5Stack CoreS3 K128 junto con todos los componentes electrónicos necesarios para el proyecto VirtualFriend: un copiloto de conducción que se comunica con el vehículo vía OBD2/CAN y muestra información en tiempo real en la pantalla del CoreS3.

La pieza está dividida en dos partes imprimibles: el cuerpo principal (frontal) y la tapa trasera desmontable, fijada con 4 tornillos M3. Las dimensiones exteriores son 112 × 52 × 106 mm con un zócalo de base de 5 mm de altura.

## 2. Vistas técnicas

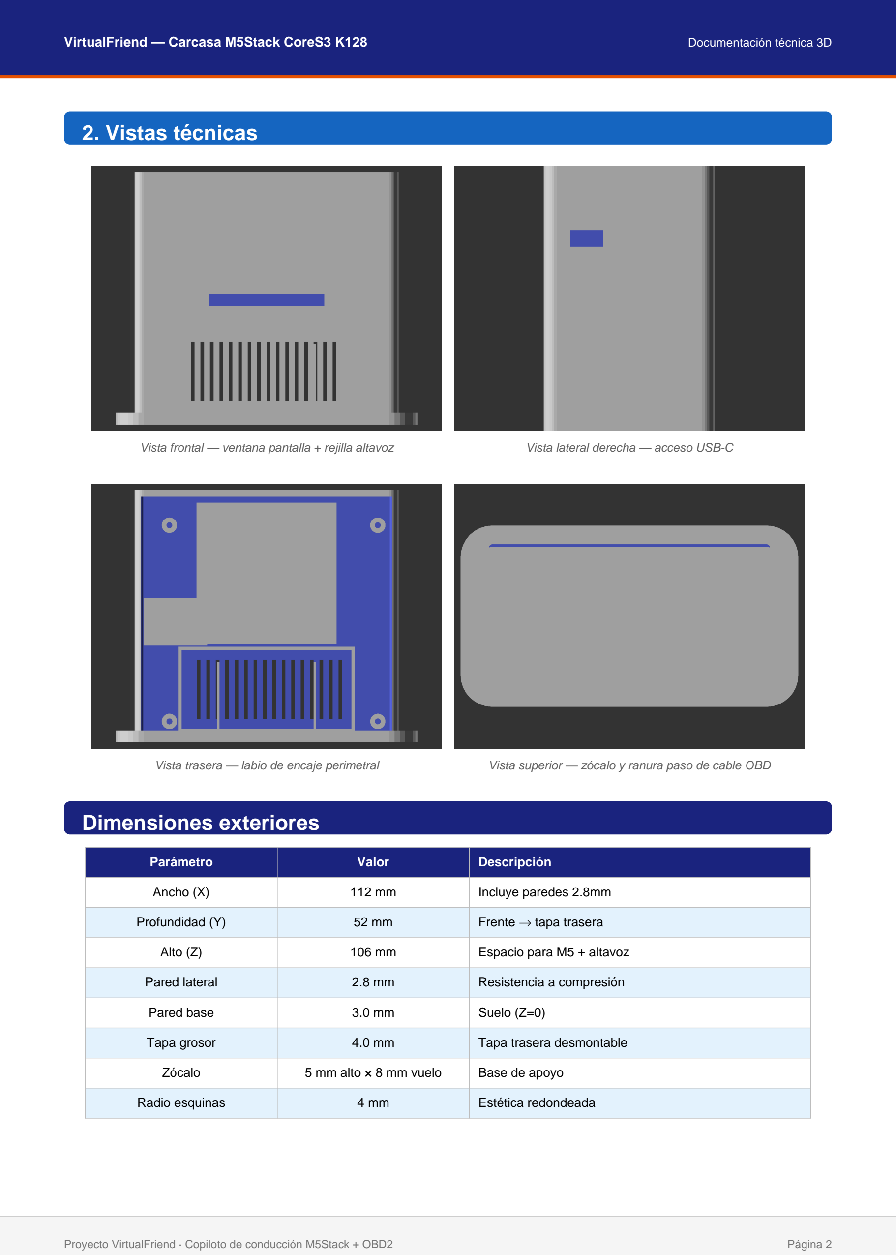
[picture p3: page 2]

Proyecto VirtualFriend · Copiloto de conducción M5Stack + OBD2 | Página 2
Vista frontal — ventana pantalla + rejilla altavoz | Vista lateral derecha — acceso USB-C
Vista trasera — labio de encaje perimetral | Vista superior — zócalo y ranura paso de cable OBD

## Dimensiones exteriores

Parámetro | Valor | Descripción
Ancho (X) | 112 mm | Incluye paredes 2.8mm
Profundidad (Y) | 52 mm | Frente → tapa trasera
Alto (Z) | 106 mm | Espacio para M5 + altavoz
Pared lateral | 2.8 mm | Resistencia a compresión
Pared base | 3.0 mm | Suelo (Z=0)
Tapa grosor | 4.0 mm | Tapa trasera desmontable
Zócalo | 5 mm alto × 8 mm vuelo | Base de apoyo
Radio esquinas | 4 mm | Estética redondeada

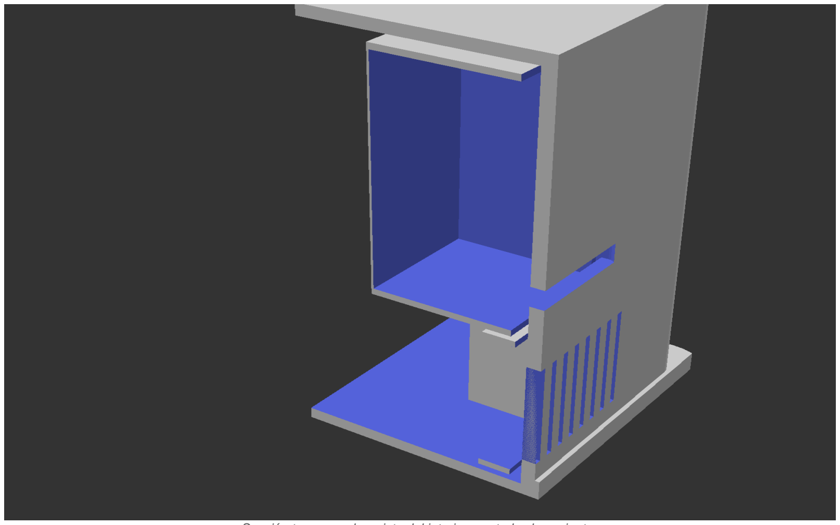
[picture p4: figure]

Proyecto VirtualFriend · Copiloto de conducción M5Stack + OBD2 | Página 3

## 3. Distribución interna de componentes

Sección transversal — vista del interior con todos los asientos

Componente | Posición X | Posición Z | Prof. (Y) | Notas
M5Stack CoreS3 K128 | Centrado (x=24.95) | Z = 39.9 mm (zona alta)
Altavoz 70×31mm (4Ω/3W) | Centrado (x=17.2) | Z = 2.9 mm (zona baja)
Amplificador MAX98357A | Derecha interior | Nivel altavoz + 2 mm | 10 mm | Apoya sobre repisa de 1.5mm de grosor
Módulo CAN / OBD | Centro (40mm ancho) | Z = 1 mm (base)

32.5 mmAsiento de 3 paredes, abierto al frente para pantalla y botones

8 mm Labio perimetral. Rejilla de ranuras verticales en cara frontal

25 mm Delimitado por 2 nervios verticales. Cable sale por ranura en base trasera

## Espacio interior útil calculado

Dimensión | Cálculo | Resultado
Ancho interior (X) | 112 − 2 × 2.8 | 106.4 mm
Alto interior (Z) | 106 − 2 × 2.8 | 100.4 mm
Profundidad útil (Y) | 52 − 3.0 − 4.0 − 2.0 | 43 mm

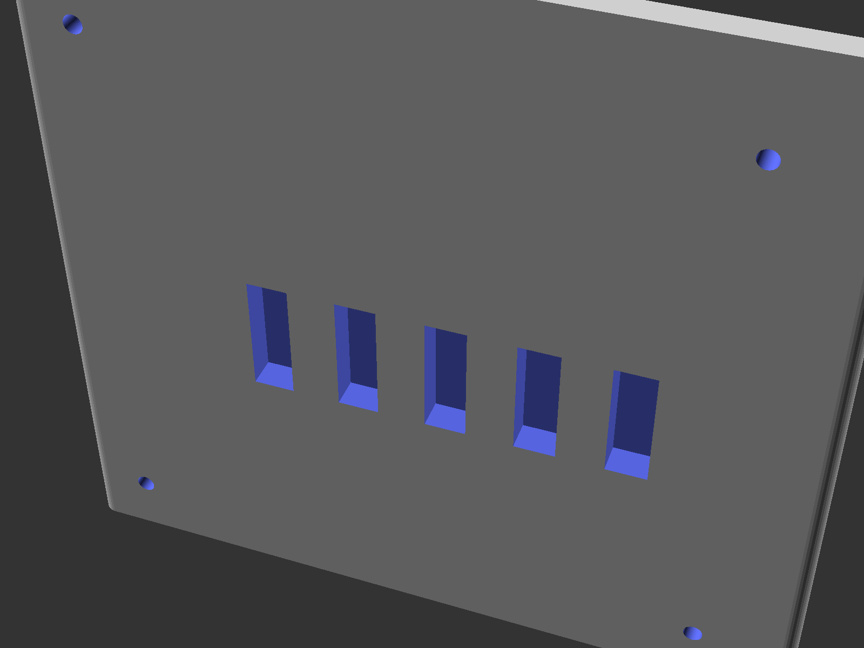
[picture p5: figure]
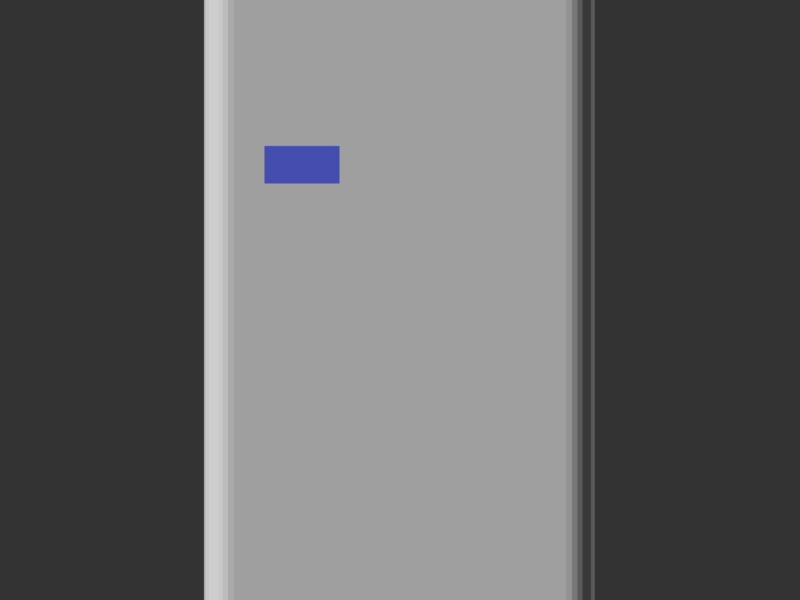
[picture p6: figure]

Proyecto VirtualFriend · Copiloto de conducción M5Stack + OBD2 | Página 4

## 4. Accesos laterales y tapa trasera

Tapa trasera — labio de encaje + ventilación + tornillos M3 | Lateral derecho — agujero USB-C (10 × 5 mm)

### Lateral derecho (X = 112 mm)

Agujero de 10 × 5 mm alineado con el puerto USB-C del CoreS3. Permite carga y programación sin desmontar la carcasa. Altura centrada con el puerto físico del módulo.

### Lateral izquierdo (X = 0)

Reservado para un futuro conector Jack 3.5 mm. Actualmente la pared está cerrada. Para instalarlo basta taladrar Ø7 mm desde fuera en la posición marcada en el SCAD (comentado con translate).

### Base trasera (Y = ext_d, Z = base)

Ranura de 20 × 4 mm centrada en X para el paso del cable del dongle OBD2. Posicionada a 2 mm sobre el nivel del zócalo para no debilitar la base.

## Tapa trasera

Característica | Detalle
Grosor | 4 mm
Labio de encaje | 2 mm, tolerancia 0.25 mm por lado
Fijación | 4 tornillos M3 · agujero pasante Ø2.8 mm + avellanado
Ventilación | 5 ranuras de 6 × 18 mm centradas verticalmente
Material recomendado | PETG o PLA+ (resistencia mecánica para los tornillos)

Proyecto VirtualFriend · Copiloto de conducción M5Stack + OBD2 | Página 5

## 5. Guía de montaje paso a paso

1

Impresión 3D

Imprimir cuerpo y tapa por separado en PETG o PLA+. Orientación recomendada: cara frontal hacia abajo (mejor acabado en ventana y rejilla). Resolución 0.2 mm, relleno 20%.

2
Post-proceso

Limpiar soportes si los hay. Roscar los 4 agujeros M3 de las columnas interiores con macho M3 o insertar heat-set inserts M3 con soldador.

3
Módulo CAN / OBD

Colocar el módulo en la zona central baja (entre los dos nervios). Conectar el cable OBD2 y sacarlo por la ranura de la base trasera.

4
Amplificador MAX98357A

Apoyar el amplificador sobre su repisa lateral derecha. Fijar con un punto de cola caliente si es necesario.

5
Altavoz 70×31mm

Encajar el altavoz en su asiento (labio perimetral). La membrana debe quedar alineada con la rejilla frontal. Conectar al MAX98357A antes de cerrar.

6

M5Stack CoreS3

Insertar el CoreS3 en su asiento de tres paredes. La pantalla queda alineada automáticamente con la ventana frontal (50.5 × 42 mm). El puerto USB-C debe coincidir con el agujero lateral derecho.

7
Cableado interno

Gestionar cables con bridas pequeñas. El espacio libre trasero es de 43 mm de profundidad. Dejar margen para que la tapa cierre sin pinzar cables.

8
Cerrar con tapa

Encajar la tapa (el labio entra en el cuerpo). Atornillar los 4 tornillos M3 en diagonal (no en orden lineal) para asegurar un cierre uniforme.

Archivo fuente: virtualfriend_carcasa.scad — cambiar la variable PIEZA entre "cuerpo", "tapa", "ambas" o "seccion" para exportar cada parte.

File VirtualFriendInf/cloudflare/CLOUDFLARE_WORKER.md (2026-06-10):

# Cloudflare Worker — VirtualFriend

## Datos del despliegue

| Campo | Valor |
|---|---|
| Nombre del Worker | `virtualfriend-worker` |
| URL pública | `https://virtualfriend-worker.rykhjob.workers.dev` |
| Subdominio Cloudflare | `rykhjob.workers.dev` |
| Account ID | `5ec1e21526952b525dd63b8e66571d3b` |
| Email cuenta | `rykhjob@gmail.com` |

---

## Secrets guardados en Cloudflare

| Secret | Descripción |
|---|---|
| `GEMINI_API_KEY` | API key de Google Gemini (guardada en Escritorio/Proyecto/Api/Gemini.txt) |
| `DEVICE_TOKEN` | `(ver src/Secrets.h — no publicar)` |

> Los secrets NO están en el código. Están en Cloudflare de forma segura.

---

## Carpeta del proyecto

```
~/Proyectos/virtualfriend-worker/
  src/
    index.js          ← lógica principal del Worker
  test/
    index.spec.js     ← tests de validación
  wrangler.jsonc      ← configuración de Wrangler
  .dev.vars           ← secrets locales para desarrollo (no en git)
  package.json
```

---

## Cómo usar el Worker desde el M5Stack

### Petición HTTP

```
Método:  POST
URL:     https://virtualfriend-worker.rykhjob.workers.dev
```

### Cabeceras obligatorias

```
Content-Type: application/json
X-Device-Token: (ver src/Secrets.h — no publicar)
```

### Body (JSON)

```json
{
  "message": "Haz un comentario sarcástico sobre este viaje",
  "mood": "sarcastico",
  "movement": "normal"
}
```

### Respuesta del Worker

```json
{
  "text": "Ah, sí, otro viaje para añadir a la colección.",
  "expression": "sarcastic",
  "sound": "none"
}
```

### Valores válidos

| Campo | Valores posibles |
|---|---|
| `expression` | `happy`, `sarcastic`, `serious`, `surprised`, `sleepy` |
| `sound` | `none`, `laugh`, `beep`, `warning` |

---

## Códigos de error

| HTTP | Causa |
|---|---|
| `405` | Método no es POST |
| `401` | Token ausente o incorrecto |
| `400` | Campo `message` vacío o ausente |
| `500` | Error interno — el Worker devuelve respuesta de fallback |

---

## Comandos útiles

```bash
cd ~/Proyectos/virtualfriend-worker

# Servidor local de desarrollo
npx wrangler dev

# Ver logs en tiempo real del Worker desplegado
npx wrangler tail

# Desplegar nueva versión
npx wrangler deploy

# Ver secrets guardados
npx wrangler secret list

# Ejecutar tests
npm test
```

---

## Notas técnicas importantes

- **Gemini 2.5 Flash** es un modelo "thinking" — consume tokens pensando antes de responder.
  Se desactivó el thinking (`thinkingBudget: 0`) para respuestas rápidas y predecibles en el coche.
- **TLS en este equipo**: hay un problema con TLS 1.3 + ECH en CachyOS. Para probar con curl usar `--tlsv1.2 --tls-max 1.2`. El M5Stack no tiene este problema, usa TLS estándar.
- **Arquitectura futura**: la carpeta `src/providers/` está prevista para añadir OpenAI, Claude, Mistral, Groq, xAI sin tocar `index.js`.

---

*Creado: 2026-06-03 — Sesión 4*

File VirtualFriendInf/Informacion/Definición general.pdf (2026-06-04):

# Definición general

La idea es crear un compañero virtual que acompañe a los pasajeros durante los viajes en coche. No sería simplemente un asistente básico, sino una especie de copiloto digital con personalidad propia: humorístico, sarcástico, carismático y capaz de soltar comentarios graciosos cuando toca, pero también de ponerse serio cuando la situación lo requiera.

Este compañero virtual podrá mantener conversaciones simples con los pasajeros, detectar voces y responder de forma natural según el contexto. Su objetivo no será solo dar información, sino hacer que el viaje sea más entretenido, más dinámico y menos solitario.

Además, contará con la capacidad de reaccionar a estímulos externos del vehículo. Podrá detectar situaciones como frenazos bruscos, volantazos, aceleraciones repentinas o comportamientos anómalos durante la conducción. A través de un sistema OBD2, también podrá acceder a datos del coche, como revoluciones, errores del motor, temperatura, velocidad u otros parámetros importantes.

Una de sus funciones más características será la expresión visual mediante una pequeña pantalla OLED. En ella aparecerán animaciones que cambiarán según el estado del compañero virtual: sorpresa, sarcasmo, preocupación, burla, alerta, sueño, enfado o cualquier otra reacción personalizada. De esta forma, el asistente no solo hablará, sino que también “sentirá” visualmente lo que está ocurriendo.

También se plantea la posibilidad de incluir funciones de seguridad avanzadas, como avisos en caso de accidente. En situaciones graves, el sistema podría detectar un impacto o una anomalía importante y activar un aviso de emergencia mediante comunicación satelital o conexión móvil, con el objetivo de contactar con los servicios correspondientes.

Todas estas funciones podrán ser configurables. Para ello, existirá una aplicación opcional desde la que el usuario podrá personalizar el comportamiento del compañero: su personalidad, nivel de sarcasmo, tipo de humor, animaciones, respuestas, sensibilidad ante eventos del coche y otras preferencias.

Por último, el proyecto tendrá un enfoque abierto y personalizable. Existirá un repositorio donde la comunidad podrá compartir sus propias creaciones: nuevas personalidades, packs de animaciones, estilos visuales, reacciones, voces, modificaciones y mejoras. Además, la carcasa física del dispositivo será completamente personalizable, permitiendo que cada usuario pueda darle su propio aspecto y convertirlo en algo único.

En resumen, se busca crear un copiloto digital divertido, útil y personalizable; una mezcla entre asistente, mascota virtual y sistema de apoyo para el coche. Un compañero que haga los viajes más amenos, que se ría contigo, que te vacile cuando conduzcas mal y que sepa ponerse serio cuando la carretera lo exija.

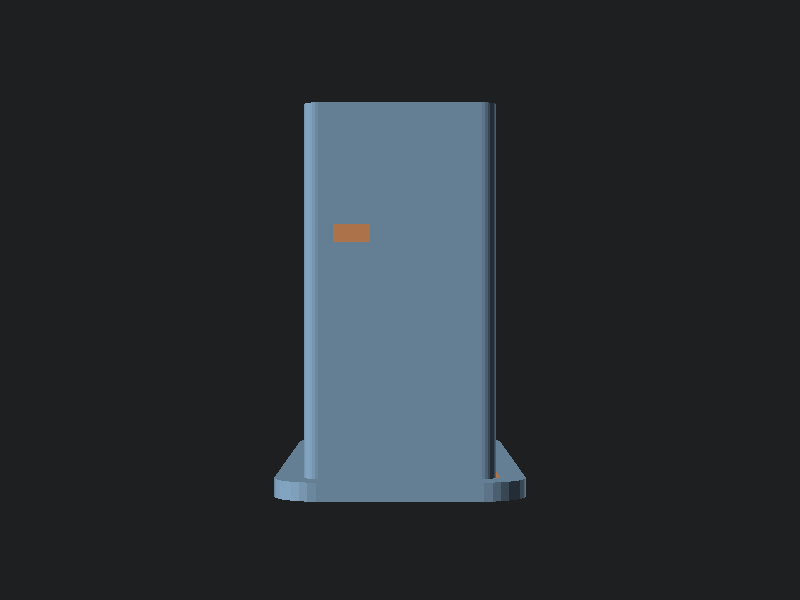
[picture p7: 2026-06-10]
carcasa/previews/virtualfriend_carcasa_left.png

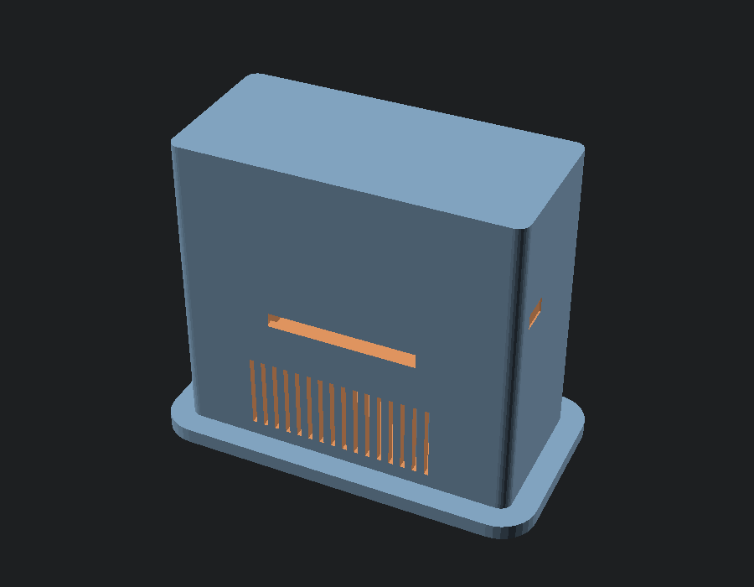
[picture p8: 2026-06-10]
carcasa/previews/cuerpo_iso.png

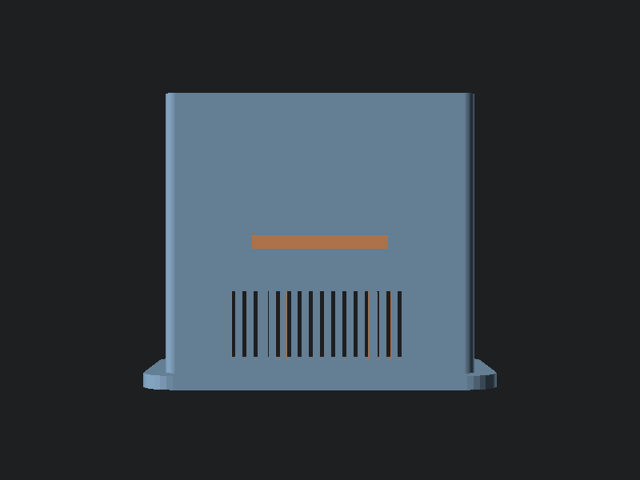
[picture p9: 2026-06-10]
carcasa/previews/virtualfriend_carcasa_front.png

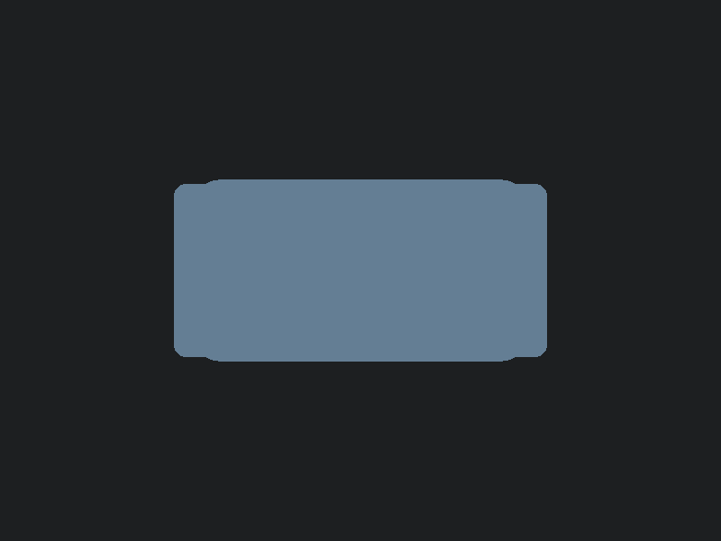
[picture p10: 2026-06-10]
carcasa/previews/virtualfriend_carcasa_top.png

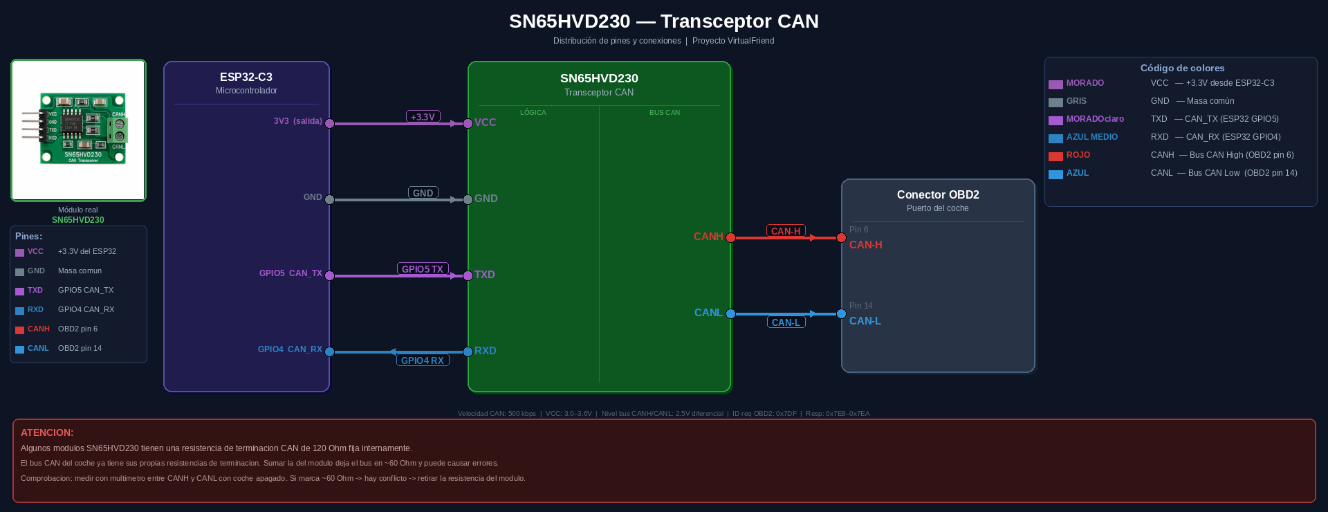
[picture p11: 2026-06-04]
VirtualFriendInf/Diagramas/DiagramaTranceptorCan_v2.png

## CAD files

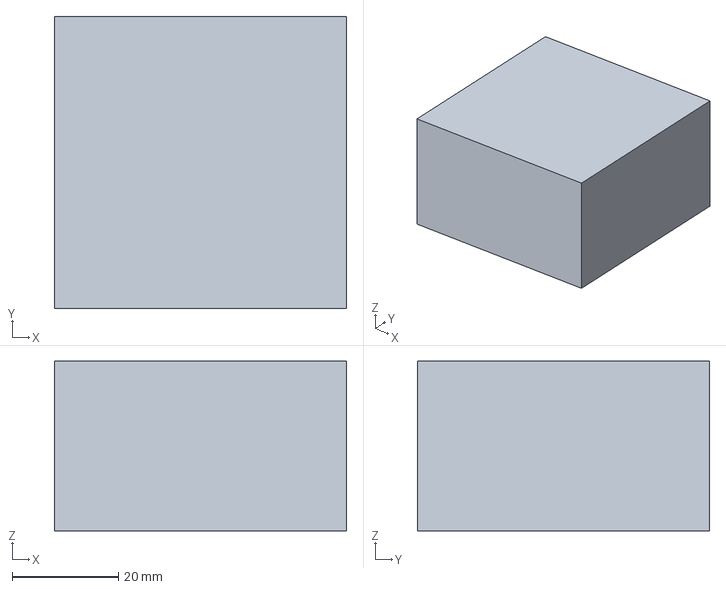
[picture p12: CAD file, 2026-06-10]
FreeCad/Prototipo1.FCStd
55.0 x 55.0 x 32.0 mm

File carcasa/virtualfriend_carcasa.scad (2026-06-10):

// ============================================================
//  VirtualFriend — Carcasa M5Stack CoreS3 K128
//  Convención de ejes: X=ancho, Y=profundidad(frente→atrás), Z=alto
//  La cara frontal (pantalla+altavoz) está en Y=0
// ============================================================
//
//  PIEZA = "cuerpo"  →  parte frontal
//  PIEZA = "tapa"    →  tapa trasera desmontable
//  PIEZA = "ambas"   →  cuerpo + tapa separada (montaje)
//  PIEZA = "seccion" →  sección en X para inspección interna

PIEZA = "ambas"; // ["cuerpo","tapa","ambas","seccion"]

$fn = 48;

// ── Exterior ──────────────────────────────────────────────
ext_w  = 112;   // Ancho  (X)
ext_d  =  52;   // Profundidad frente-atrás (Y)
ext_h  = 106;   // Alto   (Z) — 106mm para que quepan M5Stack+altavoz
r_ext  =   4;   // Radio esquinas exteriores

// ── Paredes ───────────────────────────────────────────────
pared      = 2.8;
pared_base = 3.0;   // suelo (Z=0)
tapa_d     = 4.0;   // grosor tapa trasera
tapa_lip   = 2.0;   // labio de encaje
tapa_gap   = 0.25;  // tolerancia labio

// ── Espacio interior útil ─────────────────────────────────
// int_w = ext_w - 2*pared   = 106.4 mm
// int_h = ext_h - 2*pared   = 100.4 mm
// int_d = ext_d - pared_base - tapa_d - tapa_lip = 43 mm

// ── M5Stack CoreS3 (medidas físicas +tolerancia) ──────────
m5_w = 56.5;   // X
m5_h = 56.5;   // Z (alto)
m5_d = 32.5;   // Y (profundidad)

// ── Ventana de pantalla ───────────────────────────────────
pant_w = 50.5;
pant_h = 42.0;
pant_r =  2.0;

// ── Altavoz (70×31mm, 4Ω/3W, +tolerancia) ────────────────
sp_w     = 72;   // X
sp_h     = 33;   // Z (alto del hueco)
sp_d     =  8;   // Y (profundidad asiento)
sp_margen = 4;   // espacio entre altavoz y M5Stack

// Rejilla: ranuras verticales
gr_slot  = 1.5;
gr_gap   = 2.5;
gr_marg  = 4.0;

// ── Amplificador MAX98357A ────────────────────────────────
amp_w = 25; amp_h = 18; amp_d = 10;

// ── Tornillos M3 ─────────────────────────────────────────
col_d_ext = 6.5;
col_d_int = 2.5;   // agujero roscado en cuerpo
tap_d_int = 2.8;   // agujero pasante en tapa
col_h     = 12;
col_marg  = 6;     // distancia desde esquina interior

// ── Zócalo base ───────────────────────────────────────────
base_ext  = 8;     // cuánto sobresale por cada lado
base_h    = 5;
base_r    = 3;

// ── USB-C (lateral derecho del CoreS3) ────────────────────
usb_w = 10.0;
usb_h =  5.0;

// ── Jack 3.5mm futuro (lateral izquierdo) ─────────────────
jack_d = 7.0;   // diámetro del taladro (marcado, no perforado)

// ============================================================
//  AUXILIARES
// ============================================================
module rcube(w, d, h, r) {
    r2 = min(r, d/2 - 0.01, w/2 - 0.01);  // evita colapso cuando r >= d/2
    linear_extrude(h)
        offset(r=r2, $fn=32) offset(r=-r2)
            square([w, d]);
}

module ventana(w, h, d, r) {
    linear_extrude(d + 1)
        offset(r=r, $fn=24) offset(r=-r)
            square([w, h]);
}

// Ranuras verticales de la rejilla del altavoz
module rejilla(w, h, grosor) {
    n = floor((w - gr_marg*2) / (gr_slot + gr_gap));
    for (i = [0:n-1]) {
        x = gr_marg + i*(gr_slot + gr_gap);
        translate([x, -0.5, gr_marg])
            cube([gr_slot, grosor + 1, h - gr_marg*2]);
    }
}

// Posiciones de las 4 columnas (coordenadas dentro del interior)
int_w_v = ext_w - pared*2;
int_h_v = ext_h - pared*2;

function cols() = [
    [col_marg,              col_marg],
    [int_w_v - col_marg*2,  col_marg],
    [col_marg,              int_h_v - col_marg*2],
    [int_w_v - col_marg*2,  int_h_v - col_marg*2],
];

module columna_cuerpo() {
    difference() {
        cylinder(h=col_h, d=col_d_ext);
        cylinder(h=col_h+1, d=col_d_int);
    }
}

module agujero_tapa(h) {
    cylinder(h=h+1, d=tap_d_int);
    translate([0,0,h-1.5]) cylinder(h=3, d=6.2); // avellanado
}

// ============================================================
//  POSICIONES CALCULADAS (centradas en el interior)
// ============================================================
// int_w = 106.4, int_h = 100.4
// M5Stack: centrado en X, pegado arriba con 4mm de margen
//   z_m5 = int_h - m5_h - 4 = 100.4 - 56.5 - 4 = 39.9
// Altavoz: centrado en X, justo debajo del M5Stack
//   z_sp = z_m5 - sp_h - sp_margen = 39.9 - 33 - 4 = 2.9  ← positivo ✓

int_w  = ext_w - pared*2;   // 106.4
int_h  = ext_h - pared*2;   // 100.4
int_d  = ext_d - pared_base - tapa_d - tapa_lip; // 43

x_m5   = (int_w - m5_w) / 2;               // 24.95
z_m5   = int_h - m5_h - 4;                 // 39.9
x_sp   = (int_w - sp_w) / 2;               // 17.2
z_sp   = z_m5 - sp_h - sp_margen;          // 2.9

x_pant = pared + x_m5 + (m5_w - pant_w)/2;  // 30.75
z_pant = pared + z_m5 + (m5_h - pant_h)/2;  // 50.15

x_amp  = pared + int_w - amp_w - 3;
z_amp  = pared + z_sp + sp_h + 2;

// ============================================================
//  CUERPO PRINCIPAL
// ============================================================
module cuerpo() {
    difference() {
        union() {
            // Exterior
            rcube(ext_w, ext_d, ext_h, r_ext);

            // Zócalo de base
            translate([-base_ext, -base_ext, 0])
                rcube(ext_w+base_ext*2, ext_d+base_ext*2, base_h, r_ext+base_ext);

            // Labio para encaje de tapa (cara trasera Y=ext_d)
            translate([pared-tapa_lip, ext_d-0.01, pared-tapa_lip])
                difference() {
                    rcube(int_w+tapa_lip*2, tapa_lip+0.01, int_h+tapa_lip*2, r_ext-pared+tapa_lip);
                    translate([tapa_lip, -0.5, tapa_lip])
                        rcube(int_w, tapa_lip+1.5, int_h, r_ext-pared);
                }
        }

        // ── Vaciado interior ──────────────────────────────
        translate([pared, pared_base, pared])
            rcube(int_w, int_d+tapa_d+tapa_lip+1, int_h, r_ext-pared);

        // ── Ventana pantalla (cara Y=0) ───────────────────
        translate([x_pant, -0.5, z_pant])
            ventana(pant_w, pant_h, pared+1, pant_r);

        // ── Rejilla altavoz (cara Y=0) ────────────────────
        translate([pared+x_sp, 0, pared+z_sp])
            rejilla(sp_w, sp_h, pared);

        // ── Acceso USB-C (lateral derecho X=ext_w) ────────
        translate([ext_w-0.5, pared_base+5, pared+z_m5+(m5_h-usb_h)/2])
            cube([pared+1, usb_w, usb_h]);

        // ── Hueco futuro Jack 3.5mm (lateral izq, cerrado) ─
        // Posición: lateral X=0, altura media del M5Stack
        // Para instalar: taladrar Ø7mm desde fuera
        // translate([-0.5, pared_base+8, pared+z_m5+m5_h/2])
        //     rotate([0,90,0]) cylinder(h=pared+1, d=jack_d);

        // ── Ranura paso cable OBD (base trasera) ──────────
        translate([ext_w/2-10, ext_d-pared-0.5, base_h+2])
            cube([20, pared+1, 4]);
    }

    // ── Columnas de tornillo ──────────────────────────────
    translate([pared, pared_base, pared]) {
        for (p = cols()) {
            translate([p[0], 0, p[1]])
                rotate([-90,0,0])
                    columna_cuerpo();
        }
    }

    // ── Asiento M5Stack (3 paredes laterales) ─────────────
    translate([pared+x_m5-1.5, pared_base, pared+z_m5-1.5]) {
        difference() {
            cube([m5_w+3, m5_d+1.5, m5_h+3]);
            // hueco para el M5Stack
            translate([1.5, 0, 1.5])
                cube([m5_w, m5_d+1, m5_h]);
            // apertura frontal (pantalla y botones)
            translate([-0.5, -0.5, -0.5])
                cube([m5_w+4, 4, m5_h+4]);
        }
    }

    // ── Asiento altavoz (labio perimetral) ────────────────
    translate([pared+x_sp-1.5, pared_base, pared+z_sp-1.5]) {
        difference() {
            cube([sp_w+3, sp_d+1.5, sp_h+3]);
            translate([1.5, 1.5, 1.5])
                cube([sp_w, sp_d+1, sp_h]);
            translate([-0.5, -0.5, -0.5])
                cube([sp_w+4, 3, sp_h+4]);
        }
    }

    // ── Repisa amplificador ───────────────────────────────
    translate([x_amp, pared_base+sp_d+2, z_amp])
        cube([amp_w+2, 1.5, amp_h+2]);

    // ── Nervios zona CAN/OBD (marcadores visuales) ────────
    can_x0 = pared + (int_w-40)/2;
    can_z0 = pared + 1;
    translate([can_x0-1, pared_base, can_z0]) cube([1, 25, 30]);
    translate([can_x0+40, pared_base, can_z0]) cube([1, 25, 30]);
}

// ============================================================
//  TAPA TRASERA
// ============================================================
module tapa() {
    difference() {
        union() {
            rcube(ext_w, tapa_d, ext_h, r_ext);

            // Labio de encaje
            translate([pared-tapa_lip+tapa_gap,
                       tapa_d-0.01,
                       pared-tapa_lip+tapa_gap])
                rcube(int_w+tapa_lip*2-tapa_gap*2,
                      tapa_lip+0.01,
                      int_h+tapa_lip*2-tapa_gap*2,
                      r_ext-pared+tapa_lip-tapa_gap);
        }
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

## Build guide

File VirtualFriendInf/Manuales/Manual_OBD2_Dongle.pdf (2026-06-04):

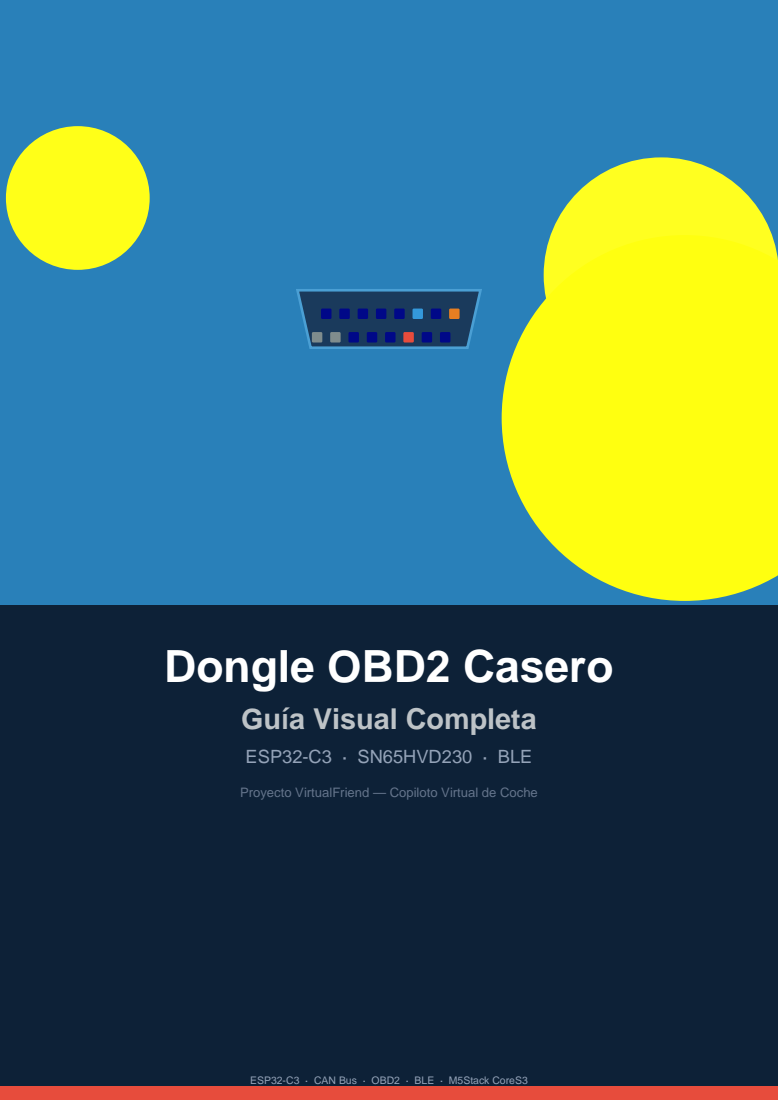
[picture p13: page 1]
ESP32-C3 · SN65HVD230 · BLE

Dongle OBD2 Casero
Guía Visual Completa

Proyecto VirtualFriend — Copiloto Virtual de Coche

ESP32-C3 · CAN Bus · OBD2 · BLE · M5Stack CoreS3

Manual Dongle OBD2 — Proyecto VirtualFriend | Pág. 2

ESP32-C3 · SN65HVD230 · CAN Bus · BLE

# ÍNDICE DE CONTENIDOS

1. Objetivo y Visión General del Proyecto
2. Lista de Componentes Necesarios
3. Puerto OBD2 — Pines y Función
4. Arquitectura del Sistema
5. Función de Cada Componente
6. Diagrama de Cableado Completo
7. Montaje Paso a Paso
8. Comprobaciones Previas con Multímetro
9. Protocolo de Pruebas Progresivas
10. Comunicación OBD2 — Cómo Funciona
11. Envío de Datos por BLE
12. Solución de Problemas Comunes
13. Reglas de Seguridad

Manual Dongle OBD2 — Proyecto VirtualFriend | Pág. 3

# 1. Objetivo y Visión General del Proyecto

El objetivo de este proyecto es construir un dongle OBD2 propio que se conecte al puerto OBD2 del coche, lea datos básicos del vehículo mediante el protocolo CAN/OBD2 y transmita esos datos por Bluetooth Low Energy (BLE) a un dispositivo receptor — en este caso un M5Stack CoreS3 que actúa como copiloto virtual.

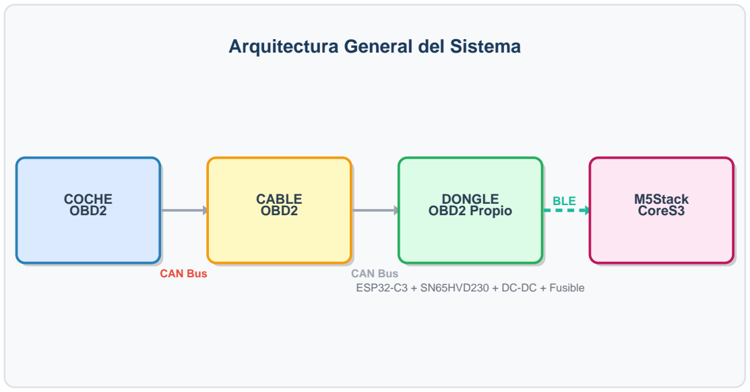
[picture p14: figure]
Arquitectura General del Sistema; COCHE OBD2; CABLE OBD2; DONGLE OBD2 Propio; BLE; M5Stack; CoreS3; ESP32-C3 + SN65HVD230 + DC-DC + Fusible; CAN Bus

El dongle actúa como intermediario entre el bus CAN del coche y el M5Stack.

Datos que se leerán en esta primera fase

- RPM del motor (PID 0x0C)
- Velocidad del vehículo en km/h (PID 0x0D)
- Temperatura del líquido refrigerante en °C (PID 0x05)
- Voltaje aproximado de la batería
- Códigos de error DTC — en una fase posterior

El dongle NO debe hacer nada de esto

- Escribir en ninguna centralita (ECU)
- Borrar códigos de error
- Controlar módulos (ABS, airbag, DSG…)
- Enviar comandos propietarios de fabricante

Manual Dongle OBD2 — Proyecto VirtualFriend | Pág. 4

# 2. Lista de Componentes Necesarios

Todos los componentes son económicos y fáciles de encontrar en tiendas de electrónica o en línea.

Componente | Función | Precio aprox.
ESP32-C3 | Microcontrolador principal: lee CAN, procesa datos, envía BLE | ~3–5 €
Módulo SN65HVD230 | Transceptor CAN: convierte señales lógicas a eléctrico CAN | ~1–2 €
Cable OBD2 macho a cables | Conector al puerto OBD2 del coche sin tocar nada | ~3–6 €
Conversor DC-DC 12V → 5V | Reduce el voltaje del coche de 12V a 5V para el ESP32 | ~2–4 €
Portafusible + fusible 1A | Protección eléctrica del prototipo | ~1 €
Cables Dupont | Conexiones rápidas para prototipo | ~1 €
Caja plástica ~100×60×30 mm | Aloja el circuito bajo el volante | ~2–3 €
Soldador + estaño | Para conexiones definitivas | Ya disponible
Tubo termorretráctil | Aislar conexiones soldadas | ~1 €
Multímetro | Imprescindible para verificar voltajes antes de conectar | Ya disponible

Nota importante sobre la caja

Debe ser de plástico, NUNCA metálica.
Una caja metálica puede provocar cortocircuitos si toca algún pin. Dimensiones recomendadas: 100 × 60 × 25 mm o similar.
Debe permitir pasar el cable OBD2 por un lateral.

Manual Dongle OBD2 — Proyecto VirtualFriend | Pág. 5

# 3. Puerto OBD2 — Pines y Función

El puerto OBD2 se encuentra normalmente debajo del volante, en el lado del conductor. Tiene 16 pines y proporciona tanto alimentación eléctrica como acceso al bus CAN del vehículo.

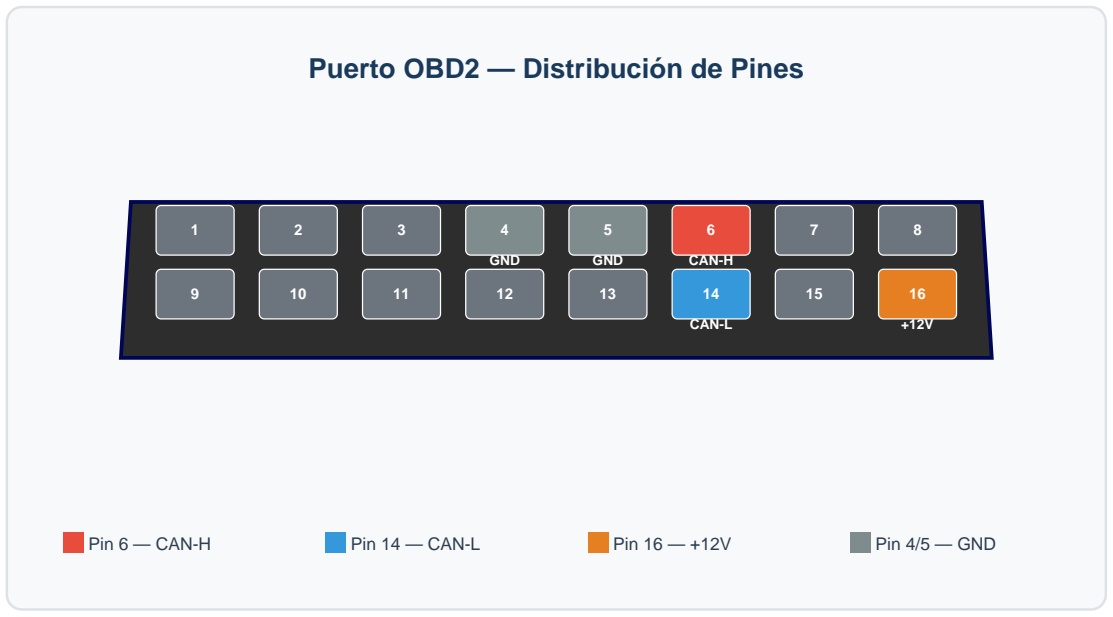
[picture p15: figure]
Puerto OBD2 — Distribución de Pines; GND; CAN-H; CAN-L; Pin 6 — CAN-H; Pin 14 — CAN-L; Pin 16 — +12V; Pin 4/5 — GND

El conector OBD2 visto de frente. Los pines resaltados son los únicos que se usan.

Pin | Señal | Descripción | Cable
4 | GND | Masa del chasis del vehículo | Negro o marrón
5 | GND | Masa de señal (a veces necesaria) | Negro o marrón
6 | CAN-H | CAN High — bus de comunicación | Naranja o amarillo
14 | CAN-L | CAN Low — bus de comunicación | Blanco o verde
16 | +12V | Alimentación directa desde batería | Rojo

IMPORTANTE — No confiar en los colores del cable

Los cables OBD2 genéricos no siguen siempre el mismo código de colores. Identificar los pines SIEMPRE por su posición física en el conector.
El pin 1 está arriba a la izquierda. El pin 16 está abajo a la derecha. Verificar con multímetro: pin 16 debe marcar ~12V respecto a pin 4/5.

Manual Dongle OBD2 — Proyecto VirtualFriend | Pág. 6

# 4. Función Detallada de Cada Componente

## 4.1. ESP32-C3 — El Cerebro del Dongle

El ESP32-C3 es el microcontrolador que coordina todo. Se encarga de gestionar el bus CAN mediante el periférico interno TWAI (Two-Wire Automotive Interface), interpretar los datos recibidos del coche y enviarlos por BLE al M5Stack CoreS3.

Capacidades del ESP32-C3

- Procesador RISC-V de 32 bits a 160 MHz
- Periférico TWAI integrado (compatible CAN 2.0)
- Bluetooth Low Energy 5.0 integrado
- Alimentación: 3.3V lógica, entrada 5V por VIN/USB
- GPIOs configurables para CAN_TX y CAN_RX

## 4.2. SN65HVD230 — El Transceptor CAN

El SN65HVD230 es imprescindible. El ESP32-C3 trabaja con señales lógicas de 3.3V, pero el bus CAN del coche usa señales diferenciales eléctricamente diferentes. El SN65HVD230 hace de traductor eléctrico entre ambos mundos.

ESP32-C3 | | SN65HVD230 | | Bus CAN del Coche
GPIO CAN_TX (3.3V lógico) | → | Pin TXD
GPIO CAN_RX (3.3V lógico) | ← | Pin RXD
| | Pin CANH | ↔ | CAN-H (Pin 6 OBD2)
| | Pin CANL | ↔ | CAN-L (Pin 14 OBD2)

Ojo: resistencia de terminación de 120Ω

Algunos módulos SN65HVD230 incluyen una resistencia de terminación fija.
El bus CAN del coche ya tiene sus propias resistencias de terminación.
Añadir otra puede alterar el bus. Si hay problemas de comunicación, revisar esto. Algunos módulos tienen un jumper para activar/desactivar la terminación.

## 4.3. Conversor DC-DC 12V → 5V

El puerto OBD2 entrega 12V directos de la batería por el pin 16. El ESP32-C3 no puede recibir 12V — se destruiría. El conversor DC-DC reduce esa tensión a 5V estables que el ESP32-C3 acepta.

Punto | Tensión | ¿Para qué?

Manual Dongle OBD2 — Proyecto VirtualFriend | Pág. 7
OBD2 Pin 16 | +12V | Alimentación del coche
Entrada DC-DC (+) | +12V | Entra al conversor
Salida DC-DC (+) | +5V | Sale del conversor → ESP32 VIN
ESP32-C3 VIN | +5V | Alimenta el ESP32
ESP32-C3 3V3 | +3.3V | Alimenta el SN65HVD230 (VCC)
GND (todo compartido) | 0V | Masa común a todos los componentes

## 4.4. Fusible de Protección

El fusible se coloca entre el pin 16 del OBD2 y la entrada del conversor DC-DC. Es la primera línea de defensa. Si algo falla y hay un cortocircuito, el fusible salta antes de que el coche sufra daños.

Valores de fusible recomendados

- RECOMENDADO: 1A (suficiente para el consumo del dongle ~200mA)
- También válido: 500mA o 2A
- NUNCA usar: fusibles de 10A, 20A o 30A para este circuito
- El fusible debe ir en el cable POSITIVO (+12V), nunca en el negativo

Manual Dongle OBD2 — Proyecto VirtualFriend | Pág. 8

# 5. Diagrama de Cableado Completo

El siguiente diagrama muestra todas las conexiones entre componentes.

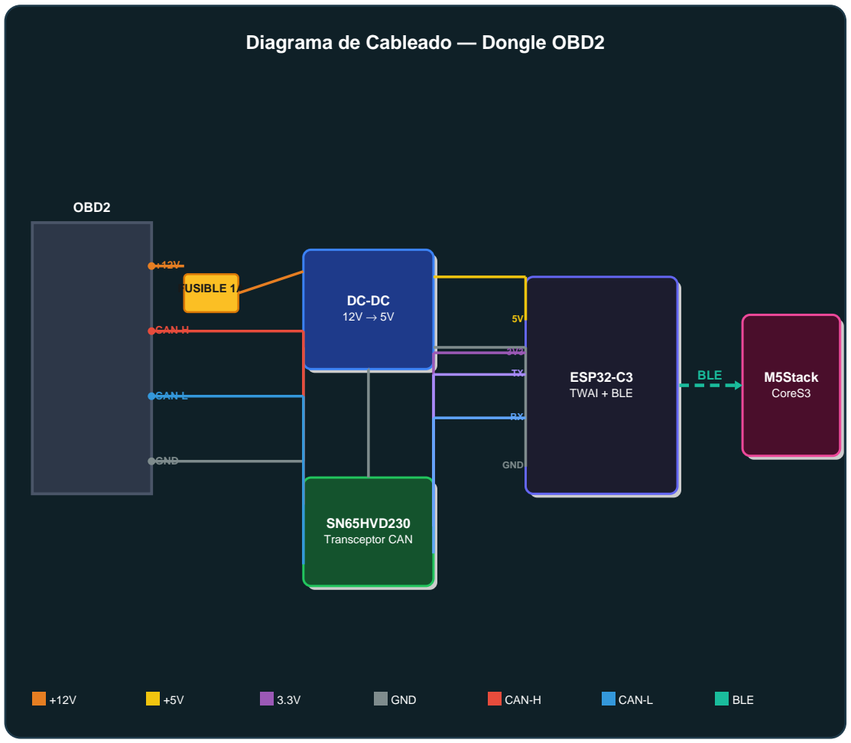
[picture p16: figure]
Diagrama de Cableado — Dongle OBD2; OBD2; CAN-H; CAN-L; GND; FUSIBLE 1A; SN65HVD230 Transceptor CAN; ESP32-C3 TWAI + BLE; M5Stack CoreS3; BLE

Diagrama esquemático del dongle OBD2 completo.

## Resumen de conexiones en tabla

Desde | Pin/Terminal | Hasta | Pin/Terminal | Color
OBD2 | Pin 16 (+12V) | Portafusible entrada | + | Naranja/Rojo
Portafusible salida | + | DC-DC entrada | VIN+ | Naranja/Rojo
OBD2 | Pin 4/5 (GND) | DC-DC entrada | GND | Negro
DC-DC salida | +5V | ESP32-C3 | 5V / VIN | Amarillo
DC-DC salida | GND | ESP32-C3 | GND | Negro
DC-DC salida | GND | SN65HVD230 | GND | Negro

Manual Dongle OBD2 — Proyecto VirtualFriend | Pág. 9
ESP32-C3 | 3.3V | SN65HVD230 | VCC | Morado
ESP32-C3 | GPIO CAN_TX | SN65HVD230 | TXD / CTX | Morado claro
ESP32-C3 | GPIO CAN_RX | SN65HVD230 | RXD / CRX | Azul claro
OBD2 | Pin 6 (CAN-H) | SN65HVD230 | CANH | Rojo
OBD2 | Pin 14 (CAN-L) | SN65HVD230 | CANL | Azul

Manual Dongle OBD2 — Proyecto VirtualFriend | Pág. 10

# 6. Montaje Paso a Paso

Seguir este orden reduce el riesgo de errores y hace más fácil localizar problemas.

PASO 1 | Preparar el cable OBD2 Identificar los pines 4/5, 6, 14 y 16 del cable OBD2. No cortar nada todavía. Marcar con cinta o rotulador cada cable.
PASO 2 | Montar el portafusible Cortar el cable del pin 16 (+12V) y soldar el portafusible en serie. Aislar con tubo termorretráctil. Colocar fusible de 1A.
PASO 3 | Conectar el conversor DC-DC Conectar +12V (desde el fusible) a la entrada + del conversor. Conectar GND (pin 4/5) a la entrada − del conversor.
PASO 4 | Verificar tensión de salida Con el multímetro, comprobar la salida del conversor. Debe ser 5.0V ± 0.2V. NO conectar el ESP32 sin haberlo verificado.
PASO 5 | Conectar ESP32-C3 al conversor Conectar la salida +5V del conversor al pin 5V/VIN del ESP32-C3. Conectar GND del conversor al GND del ESP32.
PASO 6 | Conectar SN65HVD230 al ESP32 VCC del módulo a 3.3V del ESP32. GND a GND. TXD del módulo al GPIO definido como CAN_TX. RXD al GPIO CAN_RX.
PASO 7 | Conectar SN65HVD230 al bus CAN CANH del módulo al pin 6 del OBD2. CANL del módulo al pin 14 del OBD2. NO invertir estos cables.
PASO 8 | Comprobar continuidad y cortocircuitos Con el multímetro en modo continuidad, verificar que +5V y GND no hacen corto. Verificar que CAN-H y CAN-L no hacen corto entre sí.
PASO 9 | Meter todo en la caja Taladrar la caja para el cable OBD2. Fijar las placas con cinta de doble cara o tornillos. Asegurar que nada se mueve ni hace contacto metálico.
PASO 10 | Conectar al coche y probar Dar el contacto (sin arrancar). Esperar 2-3 segundos. El ESP32 debe encenderse. Verificar con USB que arranca correctamente.

Manual Dongle OBD2 — Proyecto VirtualFriend | Pág. 11

# 7. Comprobaciones Previas con el Multímetro

Antes de conectar el dongle al coche por primera vez, realizar estas mediciones con el multímetro. Son obligatorias.

Verificar salida del conversor DC-DC

Verificar salida del conversor DC-DC

Conectar +12V y GND a la entrada del conversor (fuente externa o coche) Medir con el multímetro entre los terminales de salida
Resultado esperado: 5.0V (±0.2V)
Si mide 12V: el conversor no está funcionando. NO conectar el ESP32. Si mide 0V: revisar polaridad y soldaduras.

Verificar ausencia de cortocircuitos

Verificar ausencia de cortocircuitos

Modo multímetro: continuidad o resistencia
Medir entre +5V y GND → debe dar ABIERTO (sin pitido / >1MΩ)
Medir entre +12V y GND → debe dar ABIERTO
Medir entre CAN-H y CAN-L → debe dar ABIERTO (sin cortocircuito)
Si hay continuidad donde no debe haber → revisar cableado antes de continuar.

Verificar identificación de pines OBD2

Verificar identificación de pines OBD2

Con el coche con el contacto dado (no arrancado)
Medir entre pin 16 y pin 4: debe marcar ~12V
Medir entre pin 16 y pin 5: debe marcar ~12V
Si no hay voltaje, el coche puede tener el OBD2 sin alimentar (raro).
Los pines 6 y 14 (CAN) no se miden con voltímetro normal — son señales diferenciales.

Manual Dongle OBD2 — Proyecto VirtualFriend | Pág. 12

# 8. Protocolo de Pruebas Progresivas

No empezar conectando todo al coche de golpe. Seguir esta secuencia de pruebas reduce el riesgo y facilita el diagnóstico.

PRUEBA 1
ESP32-C3 por USB

Conectar el ESP32-C3 al ordenador por USB. Cargar un sketch básico. Abrir el Monitor Serie y verificar que aparece el mensaje de arranque. El BLE debe ser visible desde el móvil con el nombre "VirtualFriend_OBD".

PRUEBA 2
CAN con
SN65HVD230 (sin
coche)

Conectar el ESP32-C3 al módulo SN65HVD230. Sin conectar al coche. El código debe inicializar el periférico TWAI sin errores. En el Monitor Serie debe aparecer: "CAN inicializado correctamente".

PRUEBA 3
Conversor DC-DC
aislado

Verificar con multímetro que la salida del conversor es 5.0V. Hacer esto ANTES de conectar el ESP32 a la alimentación del conversor. Si la salida es correcta, conectar el ESP32 al conversor.

PRUEBA 4
ESP32 alimentado
desde el conversor

Alimentar el ESP32 desde el conversor (12V en la entrada del conversor). El ESP32 debe arrancar correctamente. Verificar con USB solo para datos. Si la placa no gestiona bien doble alimentación, usar solo una fuente.

PRUEBA 5
Conexión al OBD2
del coche

Conectar el dongle al puerto OBD2. Dar el contacto. Primera petición a enviar: RPM (PID 0x0C). Si hay respuesta, el sistema funciona. Si no, revisar la sección de problemas.

Manual Dongle OBD2 — Proyecto VirtualFriend | Pág. 13

# 9. Comunicación OBD2 — Cómo Funciona

OBD2 es un protocolo estándar de diagnóstico a bordo. En coches modernos suele correr sobre el bus CAN (ISO 15765-4) a 500 kbps. El dongle envía peticiones con un ID específico y el coche responde.

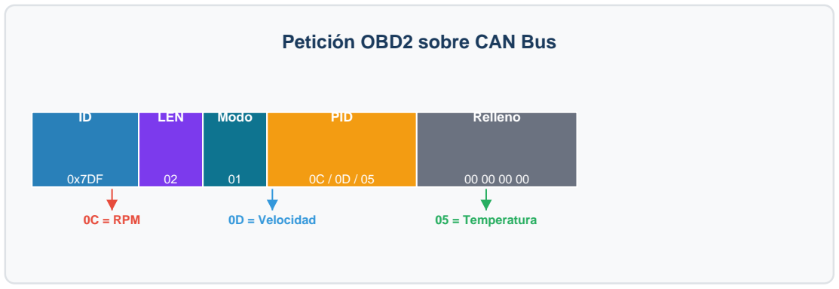
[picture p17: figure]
Petición OBD2 sobre CAN Bus; LEN; Modo; PID; Relleno

0C = RPM | 0D = Velocidad | 05 = Temperatura

Estructura de una petición OBD2 sobre CAN Bus.

## 9.1. Velocidad del Bus CAN

Velocidad | Uso | ¿Cuándo usarla?
500 kbps | OBD2 estándar moderno | Primera opción para coches a partir de 2008 aprox.
250 kbps | Buses secundarios, algunos coches más antiguos | Si 500 kbps no responde
125 kbps | Buses lentos, raro en OBD2 | Raramente necesario

## 9.2. PIDs OBD2 Básicos

Modo 01 = Datos actuales del vehículo. Los PIDs son identificadores de parámetros.

PID (hex) | Dato | Fórmula de cálculo | Unidad
0x0C | RPM | ((Byte_A × 256) + Byte_B) ÷ 4 | rpm
0x0D | Velocidad | Byte_A | km/h
0x05 | Temperatura refrigerante | Byte_A − 40 | °C
0x0B | Presión MAP | Byte_A | kPa
0x0F | Temp. aire admisión | Byte_A − 40 | °C
0x11 | Posición acelerador | (Byte_A × 100) ÷ 255 | %
0x42 | Voltaje módulo control | ((Byte_A × 256) + Byte_B) ÷ 1000 | V

Manual Dongle OBD2 — Proyecto VirtualFriend | Pág. 14

## 9.3. Secuencia de Comunicación

Pas o | Quién | Qué sucede
1 | Dongle | Envía petición al ID 0x7DF: "Dame las RPM" (PID 0x0C)
2 | Bus CAN | La trama se propaga por los cables CAN-H y CAN-L
3 | ECU del coche | Detecta la petición, lee el valor de RPM del motor
4 | ECU del coche | Responde con ID 0x7E8 con los bytes del valor de RPM
5 | Dongle | Recibe la respuesta, aplica la fórmula: ((A×256)+B)/4
6 | Dongle | Envía por BLE al M5Stack: "rpm=1850"

Manual Dongle OBD2 — Proyecto VirtualFriend | Pág. 15

# 10. Envío de Datos por BLE al M5Stack CoreS3

El ESP32-C3 actúa como servidor BLE GATT. El M5Stack CoreS3 actúa como cliente BLE que se suscribe a las notificaciones. El dongle publica los datos cada vez que hay nuevos valores.

Elemento BLE | Valor | Descripción
Nombre del dispositivo | "VirtualFriend_OBD" | Nombre visible al escanear BLE
UUID Servicio | 0x181C (o UUID custom) | Servicio OBD2 del dongle
UUID Característica | UUID custom | Característica donde se publican los datos
Tipo | NOTIFY | El M5Stack recibe datos sin tener que pedirlos
Frecuencia envío | ~500ms - 1s | Actualización periódica de los valores

## Formato de datos enviados por BLE

Se recomiendan dos opciones de formato. La segunda es más fácil de depurar al principio:

Formato | Ejemplo | Ventaja
JSON | {"rpm":1850,"speed":72,"coolant":91,"status":"ok "} | Estándar, fácil de parsear en cualquier lenguaje
Texto simple | rpm=1850;speed=72;coolant=91 | Más ligero, más fácil de depurar en el Monitor Serie

Separación de responsabilidades

DONGLE (ESP32-C3): leer CAN, consultar OBD2, convertir bytes, enviar BLE.
M5STACK (CoreS3): recibir BLE, mostrar cara, cambiar expresiones, reproducir sonidos. El M5Stack NO debe interpretar tramas CAN directamente.
El dongle le pasa los datos ya limpios y calculados.

Manual Dongle OBD2 — Proyecto VirtualFriend | Pág. 16

# 11. Solución de Problemas Comunes

No hay respuesta del coche

- El coche no tiene el contacto dado
- CAN-H y CAN-L están invertidos en el cable OBD2
- GND no está conectado correctamente (masa no común)
- Velocidad CAN incorrecta (probar 250 kbps si falla 500 kbps)
- Pines CAN_TX / CAN_RX intercambiados en el ESP32
- El módulo SN65HVD230 no está bien alimentado (comprobar 3.3V)
- El cable OBD2 tiene los pines mal identificados

El ESP32 se reinicia continuamente

- El conversor DC-DC es inestable o no entrega 5V estables
- La salida del conversor no está bien ajustada — medirla de nuevo
- Hay un cable suelto que hace contacto intermitente
- Cortocircuito parcial en el cableado
- La corriente es insuficiente (conversor de muy baja potencia)

El coche muestra un aviso o error

- DETENER la prueba inmediatamente
- Desconectar el dongle del OBD2
- Revisar el cableado en busca de cortos
- Comprobar la resistencia de terminación CAN del módulo
- Reducir la frecuencia de las peticiones OBD2
- Asegurarse de no enviar comandos de escritura ni propietarios

Se calienta algún componente

- Desconectar INMEDIATAMENTE del OBD2
- Buscar cortocircuito: +12V o +5V en corto con GND
- Verificar polaridad del conversor DC-DC
- Comprobar si el fusible ha saltado
- Revisar si algún cable pelado toca la caja o una pista metálica

BLE no es visible desde el M5Stack

- El ESP32 no está encendido o no ha arrancado correctamente
- El nombre del dispositivo BLE no coincide con lo que busca el M5Stack
- El ESP32 ya tiene una conexión activa (BLE solo permite 1 conexión)
- El sketch no inicializa el servidor BLE correctamente
- Distancia demasiado grande — probar a menos de 1 metro

Manual Dongle OBD2 — Proyecto VirtualFriend | Pág. 17

# 12. Reglas de Seguridad

■ REGLAS DE SEGURIDAD — NO IGNORAR

NUNCA escribir en ninguna ECU o centralita del coche

NUNCA borrar códigos de error (DTC) sin autorización

NUNCA controlar módulos: ABS, airbag, dirección, inmovilizador, DSG

NUNCA enviar comandos propietarios del fabricante

NUNCA programar la ECU desde el dongle

Solo leer PIDs OBD2 estándar del Modo 01

Usar siempre fusible en el cable de +12V

Usar siempre caja plástica cerrada para alojar el circuito

Medir siempre con multímetro antes de conectar al coche

No dejar placas sueltas ni cables sin aislar debajo del volante

Si el coche muestra algún aviso: desconectar inmediatamente

Si algo se calienta: desconectar inmediatamente

Objetivo del primer prototipo funcional

✓ ESP32-C3 conectado al OBD2 y comunicándose por CAN ✓ Lectura de RPM en el Monitor Serie
✓ Lectura de velocidad en km/h
✓ Lectura de temperatura del refrigerante
✓ Envío de los tres datos por BLE al M5Stack CoreS3

→ Una vez esto funcione, se puede añadir más: voltaje, DTCs, datos propietarios VW...

Este manual forma parte del proyecto VirtualFriend. El dongle OBD2 es el primer componente de un sistema de copiloto virtual basado en IA para el coche.

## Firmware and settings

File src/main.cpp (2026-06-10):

#include <M5Unified.h>
#include "Config.h"
#include "FaceRenderer.h"
#include "ExpressionManager.h"
#include "SoundManager.h"
#include "SensorMonitor.h"
#include "AnimationPlayer.h"
#include "AiManager.h"
#include "MicManager.h"
#include "obd.h"

FaceRenderer      face;
ExpressionManager expr;

SemaphoreHandle_t g_audioMutex = nullptr;
volatile bool     g_micActive  = false;
volatile bool     g_aiThinking = false;

SoundManager           sound;  // global: AiManager también lo usa para alertas
static SensorMonitor   imu;
static OBDManager      obd;
AnimationPlayer        anim;   // global: AiManager le encola expresiones IA
static AiManager       ai;
static MicManager      mic;

// ── Tarea de control (Core 1) ─────────────────────────────────────────────────

void controlTask(void* pvParams) {
    uint32_t lastImuMs      = 0;
    uint32_t lastStackMs    = 0;
    uint32_t lastObdMs      = 0;

    while (true) {
        uint32_t now = millis();

        if (now - lastStackMs >= 10000) {
            lastStackMs = now;
            Serial.printf("[STACK] Ctrl=%u  heap=%u psram=%u\n",
                (unsigned)uxTaskGetStackHighWaterMark(nullptr),
                (unsigned)ESP.getFreeHeap(),
                (unsigned)ESP.getFreePsram());
        }

        if (now - lastImuMs >= IMU_SAMPLE_MS) {
            lastImuMs = now;
            M5.update();

            // ── Toque en pantalla → grabar audio ─────────────────────────────
            {
                static bool s_prevTouch = false;
                bool touched = M5.Touch.getCount() > 0;
                if (touched && !s_prevTouch && !mic.isRecording() && !mic.hasPending()) {
                    Serial.println("[TOUCH] Grabacion iniciada");
                    mic.triggerRecord();
                }
                s_prevTouch = touched;
            }

            // ── Audio grabado listo → enviar a IA ────────────────────────────
            if (mic.hasPending()) {
                uint8_t* buf; size_t len;
                mic.takePending(&buf, &len);
                ai.onMicAudio(buf, len); // AiTask libera el buffer
            }

            // ── IMU → eventos de conducción ───────────────────────────────────
            SensorEvent ev = imu.update();
            switch (ev) {
                case SensorEvent::HARD_ACCEL:
                    sound.play(SoundEffect::ACCEL);
                    anim.triggerEvent(AnimEvent::HARD_ACCEL);
                    ai.onEvent(ev);
                    break;

                case SensorEvent::HARD_BRAKE:
                    sound.play(SoundEffect::BRAKE);
                    anim.triggerEvent(AnimEvent::HARD_BRAKE);
                    ai.onEvent(ev);
                    break;

                case SensorEvent::BUMP:
                    sound.play(SoundEffect::BUMP);
                    anim.triggerEvent(AnimEvent::BUMP);
                    ai.onEvent(ev);
                    break;

                default: break;
            }
        }

        // ── OBD → reacciones al estado del coche ─────────────────────────────
        obd.update();
        if (obd.isConnected() && (now - lastObdMs >= OBD_REACTION_COOLDOWN_MS)) {
            if (obd.hasEngineError()) {
                anim.triggerEvent(AnimEvent::AI_SERIOUS);
                lastObdMs = now;
            } else if (obd.getEngineTemp() > OBD_TEMP_ALERT_C) {
                anim.triggerEvent(AnimEvent::AI_SERIOUS);
                lastObdMs = now;
            } else if (obd.getRPM() > OBD_RPM_ALERT) {
                anim.triggerEvent(AnimEvent::AI_SURPRISED);
                lastObdMs = now;
            } else if (obd.getSpeed() > OBD_SPEED_ALERT_KMH) {
                anim.triggerEvent(AnimEvent::AI_SERIOUS);
                lastObdMs = now;
            }
        }

        vTaskDelay(pdMS_TO_TICKS(5));
    }
}

// ── Setup ─────────────────────────────────────────────────────────────────────

void setup() {
    auto cfg = M5.config();
    M5.begin(cfg);
    Serial.begin(115200);

    g_audioMutex = xSemaphoreCreateMutex();

    face.begin();
    sound.begin();
    imu.begin();
    obd.begin();
    anim.begin();
    mic.begin();

    ai.begin(); // conecta WiFi y arranca AiTask

    randomSeed(millis());
    Serial.printf("[VirtualFriend] SD=%s  WiFi=%s\n",
        anim.sdAvailable() ? "OK" : "no",
        ai.isConnected()   ? "OK" : "sin conexion"
    );

    xTaskCreatePinnedToCore(animPlayerTask, "AnimTask", 20480, &anim, 2, nullptr, 0);
    xTaskCreatePinnedToCore(controlTask,   "CtrlTask",  8192,  nullptr, 1, nullptr, 1);
}

void loop() {
    vTaskDelay(portMAX_DELAY);
}

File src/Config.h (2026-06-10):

#pragma once

// --- Offsets IMU (posición definitiva, medidos 2026-06-03) ---
// Gravedad cae en AY (+1G) → Y es el eje vertical.
// AX y AZ son los ejes horizontales (aceleración/frenada del coche).
#define IMU_OFFSET_AX  -0.0139f
#define IMU_OFFSET_AY   1.0031f
#define IMU_OFFSET_AZ  -0.0141f

// Umbral de aceleración/frenada brusca en eje horizontal dominante (en G)
#define ACCEL_THRESHOLD     0.45f
#define BRAKE_THRESHOLD     0.40f
// Umbral de bache: delta en eje vertical (AY corregido) entre frames a 40ms
#define BUMP_THRESHOLD      0.40f

// Tiempo mínimo entre eventos del mismo tipo (ms)
#define EVENT_COOLDOWN_MS   3000

// Tiempo que se muestra una frase en pantalla (ms)
#define PHRASE_DISPLAY_MS   4000

// Frecuencia de muestreo del IMU (ms entre lecturas)
#define IMU_SAMPLE_MS       40

// Colores de texto de frase
#define COLOR_TEXT          0xFFFFFF
#define COLOR_TEXT_ALERT    0xFF4444

// --- OBD / CAN ---
// 1 = valores simulados (mientras no llegue el comunicador CAN)
// 0 = lectura real (activar cuando esté disponible el hardware)
#define OBD_SIMULATION_MODE 1

// Tiempo mínimo entre reacciones a datos OBD (ms)
#define OBD_REACTION_COOLDOWN_MS 8000

// Umbrales de reacción a datos del coche
#define OBD_TEMP_ALERT_C     95    // temperatura refrigerante alta
#define OBD_RPM_ALERT        4000  // motor revolucionado
#define OBD_SPEED_ALERT_KMH  120   // velocidad excesiva

// --- Credenciales (WiFi + token del worker) ---
// Definidas en Secrets.h (gitignorado). Plantilla: Secrets.example.h
#include "Secrets.h"

// --- Cloudflare Worker ---
#define WORKER_HOST  "virtualfriend-worker.rykhjob.workers.dev"

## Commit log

2026-06-01 Prototipo 1, basico, funcional, sin implementacion en el arduino
2026-06-04 Fase 1: M5Stack CoreS3 firmware completo
    Reemplaza el prototipo Wokwi/ESP32 generico por el firmware real para
    M5Stack CoreS3 con cara animada, voz IA, micro touch-to-talk e IMU.
    Componentes:
    - AnimationPlayer: GIFs en SD + fallback vectorial; expresiones IA
    - AiManager: cliente HTTPS del Cloudflare Worker (eventos + /listen)
    - MicManager: grabacion 3s WAV con feedback "HABLA AHORA"
    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
2026-06-04 Ajustar puerto USB a /dev/ttyACM0 para esta sesion
2026-06-04 Documentacion del proyecto en VirtualFriendInf/
    Manuales (PDF), diagramas, info OBD2, CONTEXTO.md y Puntos FD movidos
    dentro del proyecto VS Code para tenerlo todo bajo control de versiones.
2026-06-10 Capa OBD/CAN integrada en modo simulacion
    - src/obd.h + src/obd.cpp: clase OBDManager con modo simulacion
    (OBD_SIMULATION_MODE en Config.h) y TODO para lectura CAN real
    - main.cpp: obd.begin()/update() en controlTask con cooldown propio
    - Reacciones: error motor / temp>95 -> seria, RPM>4000 -> sorpresa,
    velocidad>120 -> seria
    - Doc de estado del prototipo 1 en VirtualFriendInf/Informacion/
    [Config.h, main.cpp]
2026-06-10 Carcasa: diseno OpenSCAD, modelo FreeCAD, previews y PDF tecnico
    - carcasa/virtualfriend_carcasa.scad: dos piezas para salpicadero,
    inclinada 8 grados, ventana pantalla, rejilla altavoz, tapa M3
    - carcasa/DISENO_TECNICO.md + PDF explicativo + previews renderizados
    - FreeCad/Prototipo1.FCStd
    [Prototipo1.FCStd, virtualfriend_carcasa.scad]
2026-06-10 Mover credenciales a Secrets.h gitignorado y redactar docs
    - WIFI_SSID/WIFI_PASS/WORKER_TOKEN salen de Config.h a src/Secrets.h
    (gitignorado); plantilla en src/Secrets.example.h
    - Token redactado de CONTEXTO.md y CLOUDFLARE_WORKER.md
    - Gemini.txt anadido a .gitignore
2026-06-10 Pulido: fix AnimEvent sin inicializar y umbrales OBD a Config.h
    - _animTaskLoop (modo vectorial): ev podia leerse sin inicializar si
    xQueueReceive expiraba -> animaciones espurias aleatorias
    - Umbrales de reaccion OBD (temp/RPM/velocidad) movidos a Config.h
    - SensorMonitor: eliminado miembro _lastEvent sin uso
    - obd sim: probabilidad de error corregida a 5% exacto
    [AnimationPlayer.cpp, Config.h, main.cpp]
